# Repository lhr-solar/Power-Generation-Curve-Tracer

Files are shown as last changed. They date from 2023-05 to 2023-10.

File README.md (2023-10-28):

# :sunny: PV Curve Tracer

- [:sunny: PV Curve Tracer](#sunny-pv-curve-tracer)
  - [Repository Structure](#repository-structure)
  - [Maintainers and Contribution](#maintainers-and-contribution)
  - [Versioning](#versioning)
  - [TODO](#todo)

---

## Repository Structure

- **datasheets** - contains datasheets for major components of the PV Curve Tracer.
- **docs** - contains documentation on how to build, test, and use the PV Curve Tracer.
- **fw** - contains fw that is loaded onto the PV Curve Tracer.
  - **tests** - test programs used to characterize and validate the PV Curve Tracer.
  - **src** - main program used to run the PV Curve Tracer.
  - **inc** - internally developed libraries specific for the PV Curve Tracer.
  - **lib** - third party libraries used by the PV Curve Tracer.
- **hw**
  - **Footprints** - project specfic footprint association files for the PV Curve Tracer.
  - **Models** - 3d .step files for the PCB 3d viewer.
  - **Symbols** - project specific symbol files for the PV Curve Tracer.
  - **vX_Y_Z** - frozen versioning folder for PCB production files.

---

## Maintainers and Contribution

The current maintainer of this project is Matthew Yu as of 05/20/2023. His email
is [matthewjkyu@gmail.com](matthewjkyu@gmail.com).

Contributors to the HW and FW encompass many dedicated students, including:

- Roy Mor
- Afnan Mir
- Youssef Elsherif

Special thanks to Professor Gary Hallock, who supervised the development and
design of this project.

---

## Versioning

This PCB is on unified version `1.3.0`. Every time the schematic and/or layout
is updated, this version number should go up. We use [semantic
versioning](https://semver.org/) to denote between versions. See the
[changelog](./docs/CHANGELOG.md) for more details.

---

## TODO

Documentation

- Update assembly and testing document, ordering document, and improvement document.
- Add datasheets for key components of the device.

HW

- check if v1.2.0 bodges has been fixed (op amps, regulator)
   Complete v1.4.0rc board candidate

SW

- Regenerate code for MBED with proposed filestructure

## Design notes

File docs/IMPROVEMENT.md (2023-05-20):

# IMPROVEMENTS FOR PV Curve Tracer

This is a list of changes we can make to the board in future versions to improve
it in various ways. Some of these are functional, others are purely aesthetic.

1. Built in RTD sensor.
2. Secondary UART communication line.
3. Shrink board to sub 100x100mm.
4. Use TM4C for more peripherals?

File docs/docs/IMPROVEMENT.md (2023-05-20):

# IMPROVEMENTS FOR PV Curve Tracer FW

v1.0.0

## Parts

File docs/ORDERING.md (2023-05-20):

# HOW TO ORDER THIS PCB

This guide is on revision `v1.1.0`.

Ordering the board will vary from distributor to distributor; some will take the
KiCAD project directly, others require Gerber files. If they require gerber
files, some will require specific naming conventions for each layer.

## Ordering Instructions: JLCPCB

Our preferred manufacturer (or at least mine) of choice is JLCPCB. They
manufacture hobby boards cheaply and quickly, and at relatively high quality
compared to other fab houses.

JLCPCB will manufacture 5 PCBs for 2$ (sans shipping and handling) if the PCBs
are <= 100mm * 100mm. They also have an SMD assembly surface where one side of
the PCB is populated, often for very cheap prices compared to the amount of
labor you would have to put in to solder all the components on.

For this PCB (Sunscatter), we will order from JLCPCB and also do SMD assembly
from them. KiCAD has nice, open source extensions that can quickly create build
files that JLCPCB will accept for manufacturing and assembly.

### Preparing the Gerbers

First make sure that the JLCPCB plugin is installed via the Plugin and Content
Manager.

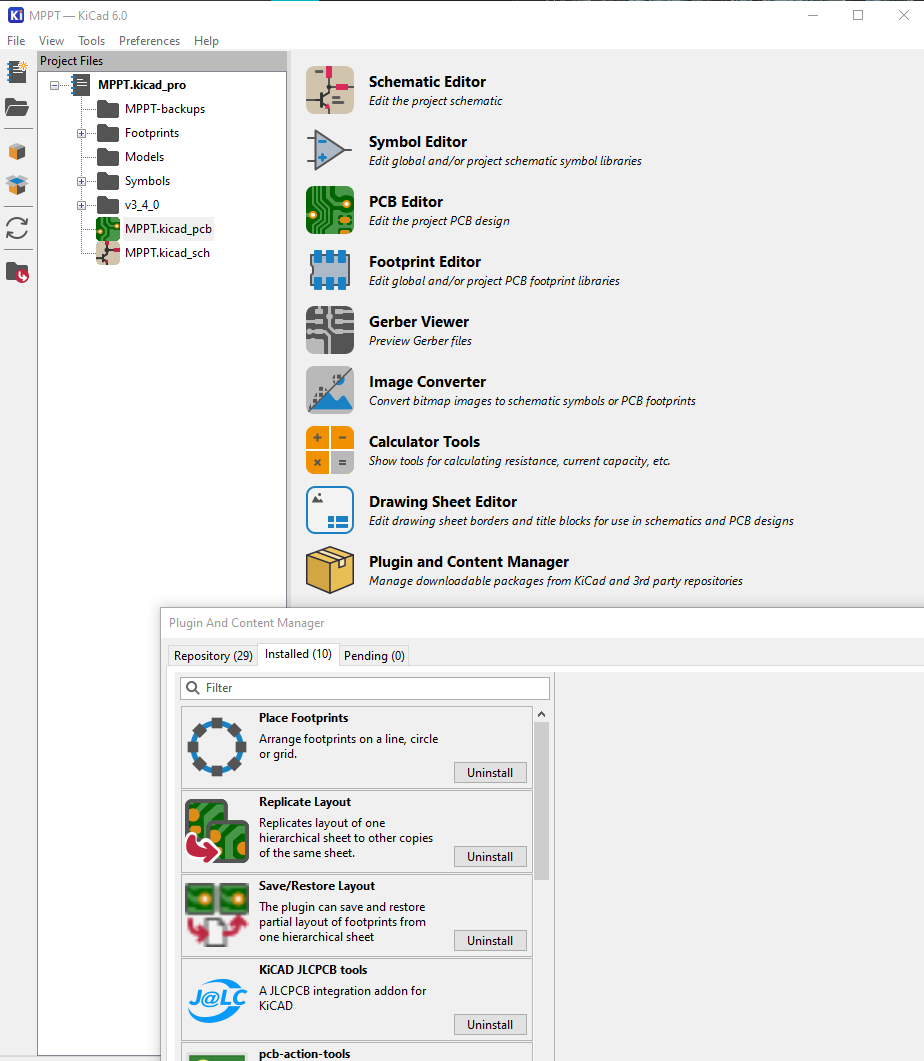
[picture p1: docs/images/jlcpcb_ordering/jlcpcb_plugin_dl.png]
Install plugin


Then make sure your schematic symbol table has following columns populated for
each component:
- Value
- Reference
- Footprint
- JLCPCB BOM
- LCSC Part

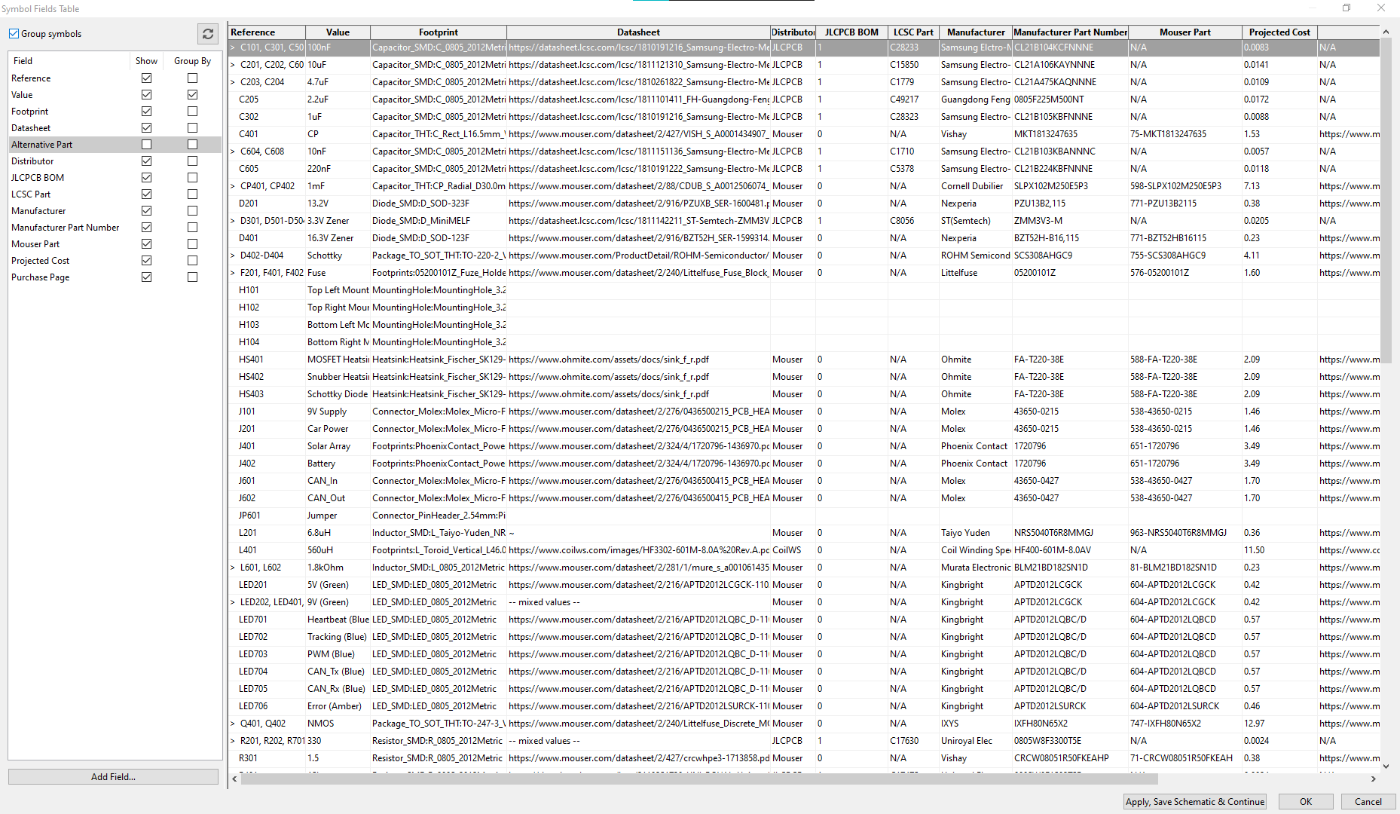
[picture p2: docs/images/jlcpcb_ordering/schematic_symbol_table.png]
Populated symbol table


Go to the PCB editor, and after the layout finishes and everything passes DRC
click on the JLCPCB button.

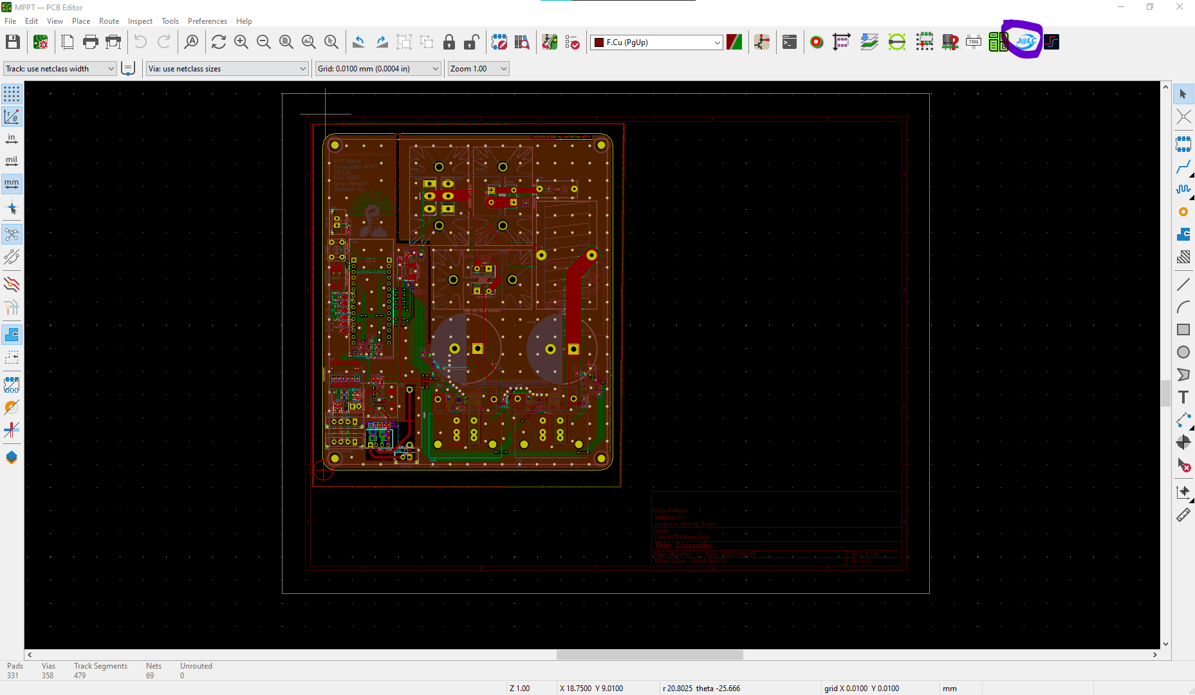
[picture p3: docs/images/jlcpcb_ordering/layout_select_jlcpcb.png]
JLCPCB buttom


Finally generate the fab files using the Generate Fabrication Files button. Make
sure the BOM and POS have a checkmark for all components you want assembled by JLCPCB.

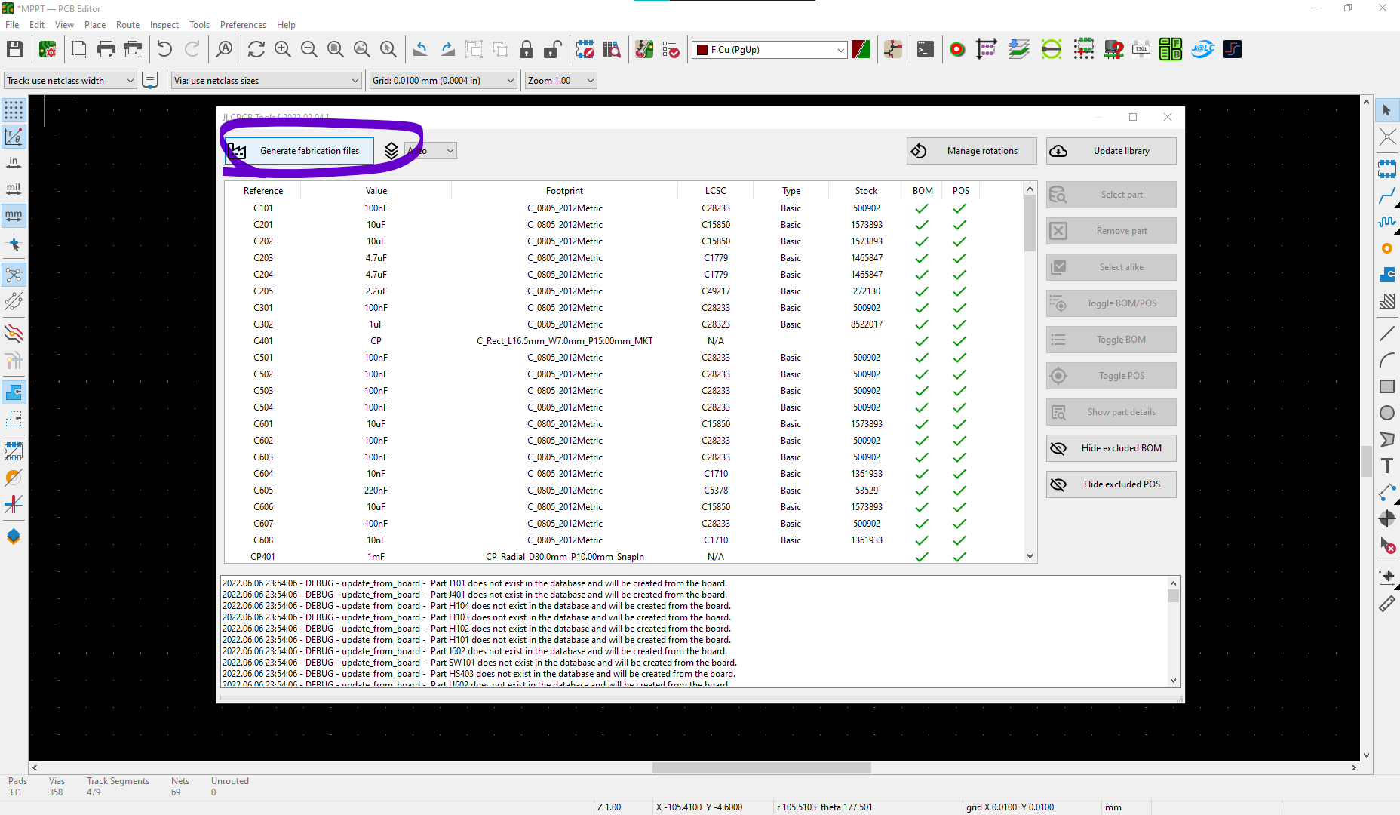
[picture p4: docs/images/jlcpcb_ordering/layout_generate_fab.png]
Generate gerbers


### Ordering from JLCPCB

After the gerbers are generated properly, head onto the JLCPCB
[site](jlcpcb.com).

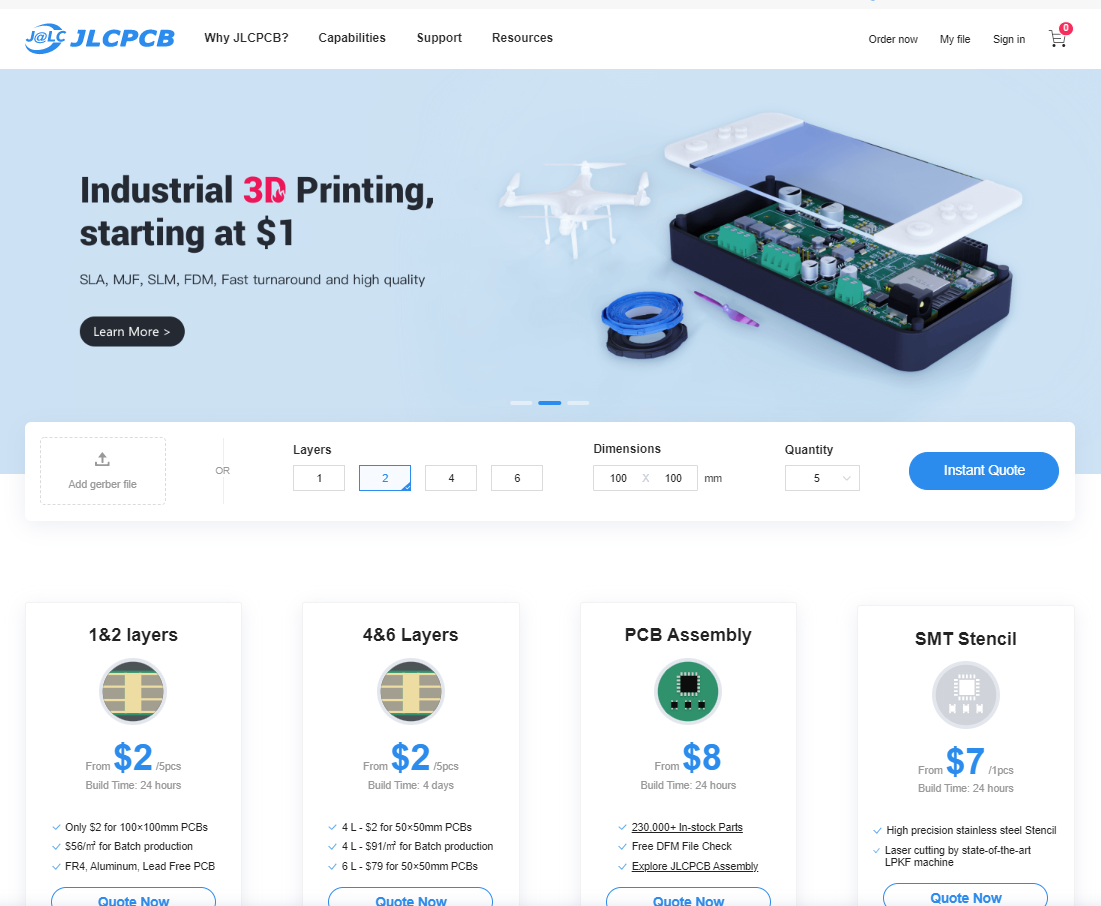
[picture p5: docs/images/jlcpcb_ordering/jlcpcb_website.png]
JLCPCB site


Go and get a quote.

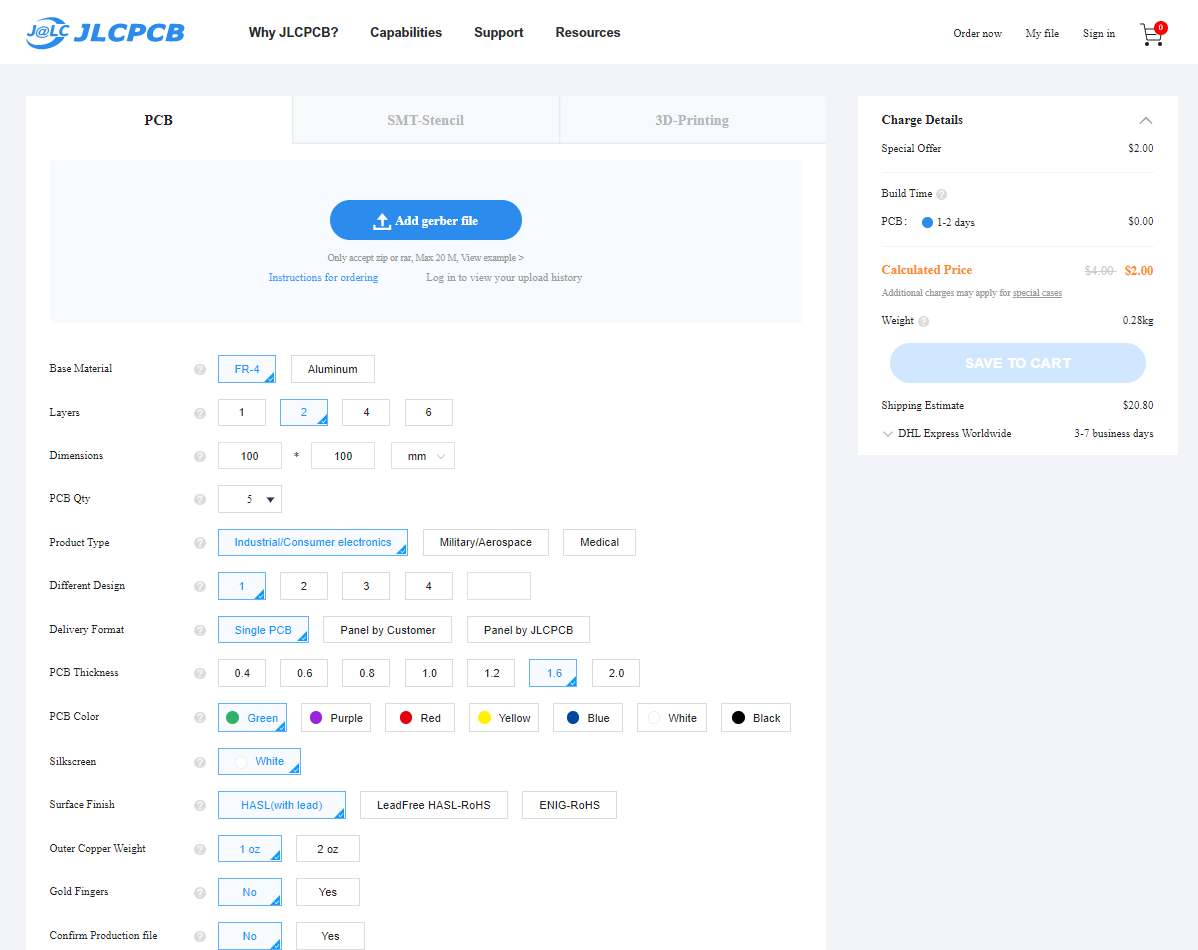
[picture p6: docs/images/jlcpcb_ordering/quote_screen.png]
JLCPCB quote


If you press the add gerber file button, you can upload the output gerber files.
They are found in the `jlcpcb/assembly/gerber` folder as `GERBER-xxx.zip`.

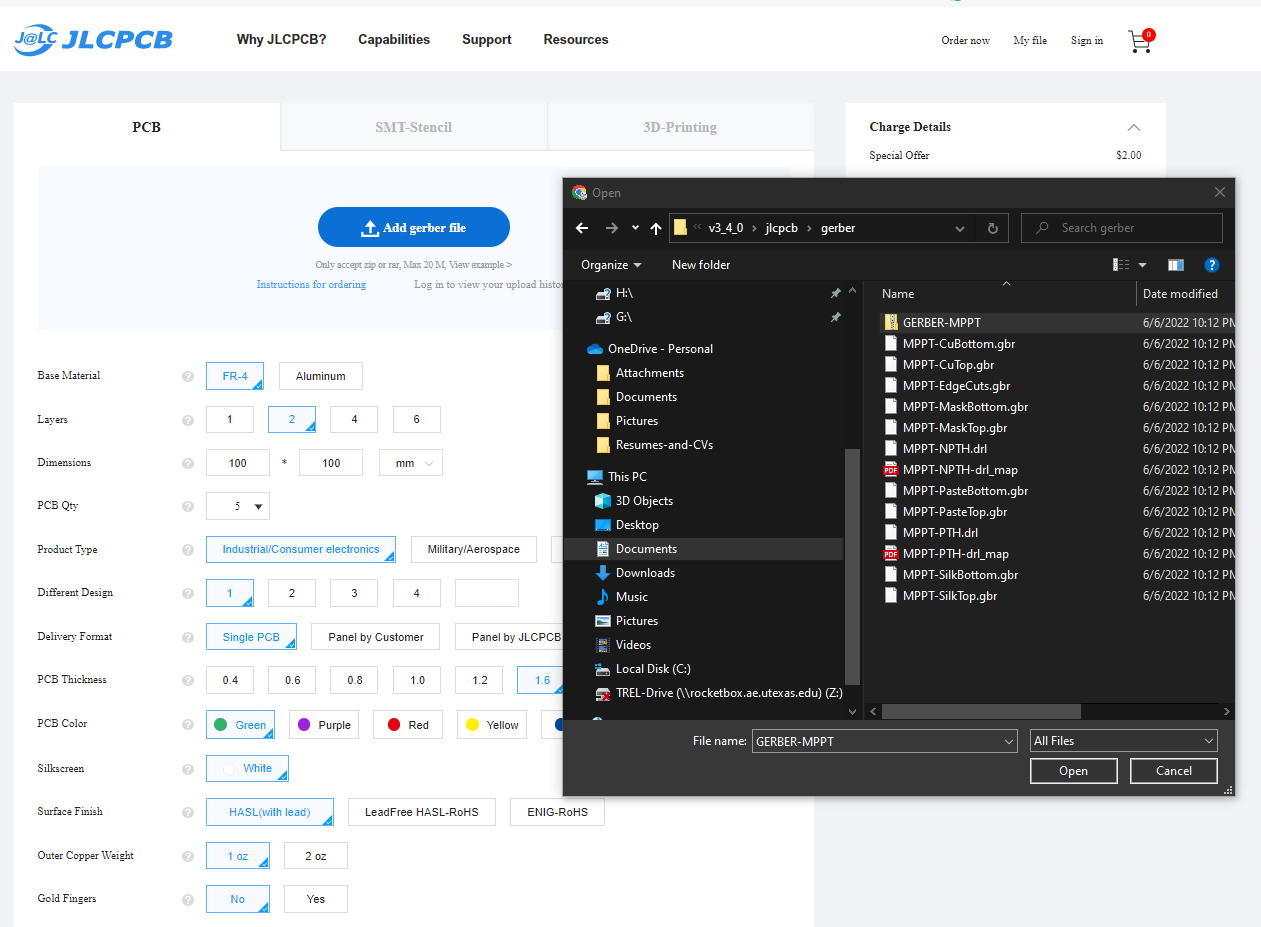
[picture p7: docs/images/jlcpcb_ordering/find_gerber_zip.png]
Adding gerbers


The webpage will load the gerbers, if they are in the correct format and board
passes some checks it'll show up. The dimensions of the board will be updated
and a new quote price will be displayed.

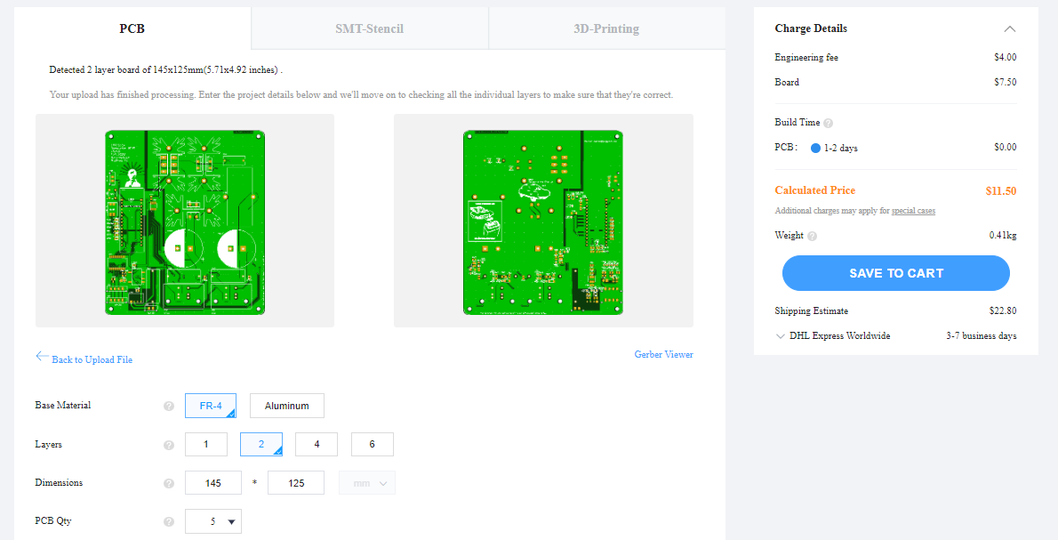
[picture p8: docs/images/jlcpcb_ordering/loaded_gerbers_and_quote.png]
New quote


We can then go down the screen and enable the PCB assembly option. We can choose
which side we want to assemble and the number of boards to assemble (2 or 5).

Assembly option

The next page after hitting confirm asks for a BOM and CPL file, the latter is
the position of the components to be assembled on the board. We can find those
as `jlcpcb/assembly/BOM-xxx.csv` and `jlcpcb/assembly/POS-xxx.csv` respectively.

Assembly file input

The next page will load the BOM and check against the LCSC internal database and
match all available components. We prefer basic components since every extended
component is an extra 2$ fee per type to manually load.

BOM matching

The next page reviews the PCB, you can zoom in on the screen to see where each
component will be placed. Make sure it matches or the engineer who inspects the
files will send an email back with complaints and the order will be delayed.

Review
Zoomed in

Finally you can save the order to the cart, review everything, and order it.
Feel free to select the delivery system that best fits your timeline and the
budget, and use any coupons if you have any.

Shopping Cart

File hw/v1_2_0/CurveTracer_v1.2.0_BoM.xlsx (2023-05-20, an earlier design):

Qty | Reference(s) | Value | Alternative Part | Distributor | Manufacturer | Part Number | Projected Cost | Purchase Page
1 | J2 | 1720819 |  | Allied | Phoenix Connector | 1720819 | 7.09 | https://www.alliedelec.com/product/phoenix-contact/1720819/71247925/
1 | F1 | Fuse |  | Mouser | Littelfuse | 576-05200101Z | 1.6 | https://www.mouser.com/ProductDetail/Littelfuse/05200101Z?qs=gu7KAQ731URy7T5v0X5a9A%3D%3D
1 | HS1 | Heatsink |  | Mouser | Ohmite | 588-FA-T220-38E | 2.09 | https://www.mouser.com/ProductDetail/Ohmite/FA-T220-38E?qs=wmFqszA%252Be7PklmA5Rej7jg%3D%3D
2 | J1, J5 | 1x2 Molex Connector |  | Mouser | Molex | 538-43650-0215 | 1.46 | https://www.mouser.com/ProductDetail/538-43650-0215
2 | J3, J4 | 1x4 Molex Connector |  | Mouser | Molex | 538-43650-0427 | 1.7 | https://www.mouser.com/ProductDetail/Molex/43650-0427?qs=yYVs2tXBqMNbk6Zhnc0cBQ%3D%3D
1 | L1 | 6.8uH |  | Mouser | Taiyo Yuden | 963-NRS5040T6R8MMGJ | 0.36 | https://www.mouser.com/ProductDetail/Taiyo-Yuden/NRS5040T6R8MMGJ?qs=y6ZabgHbY%252Bzi5243tSRdMg%3D%3D
2 | L2, L3 | 1.8kOhm |  | Mouser | Murata Electronics | 81-BLM21BD182SN1D | 0.23 | https://www.mouser.com/ProductDetail/Murata-Electronics/BLM21BD182SN1D?qs=sGAEpiMZZMvCgIIVhD0Cyg9cJWfqr1nr
4 | LED1, LED2, LED3, LED4 | Blue LED |  | Mouser | Kingbright | 604-APTD2012LQBCD | 0.57 | https://www.mouser.com/ProductDetail/Kingbright/APTD2012LQBC-D?qs=AQlKX63v8RvDGqprk6aUCg%3D%3D
1 | LED5 | Error (Amber) |  | Mouser | Kingbright | 604-APTD2012LSURCK | 0.46 | https://www.mouser.com/ProductDetail/Kingbright/APTD2012LSURCK?qs=AQlKX63v8RvkMadNvwbkxw%3D%3D
1 | LED6 | 9V (Green) |  | Mouser | Kingbright | 604-APTD2012LCGCK | 0.42 | https://www.mouser.com/ProductDetail/Kingbright/APTD2012LCGCK?qs=AQlKX63v8RvNHN%2F9EGvNTg%3D%3D
2 | Q1, Q2 | IRF100P218XKMA1 |  | Mouser | Infineon Technologies | 726-IPP041N12N3GXK | 7.07 | https://www.mouser.com/ProductDetail/Infineon-Technologies/IPP041N12N3-G?qs=wK%252BoHS4yu56MUKAoSRvNXg%3D%3D
1 | R12 | 2m | https://www.mouser.com/ProductDetail/Bourns/CRF1206-FZ-R002ELF?qs=NoqMqJKvPFJVdeqRsRJxRg%3D%3D | Mouser | ROHM Semiconductor | 755-PMR18EZPFV2L00 | 0.69 | https://www.mouser.com/ProductDetail/ROHM-Semiconductor/PMR18EZPFV2L00?qs=oBjDkOCjPF3F%252BxFCsdw8aQ%3D%3D
2 | R20, R21 | 60.4 |  | Mouser | Vishay/Dale | 71-CRCW080560R4FKEAH | 0.25 | https://www.mouser.com/ProductDetail/Vishay-Dale/CRCW080560R4FKEAHP?qs=40TFAHZMFvcOLVKmRrsypQ%3D%3D
1 | SW1 | SW_Push |  | Mouser | CUI Devices | 179-TS026650BK260SCR | 0.1 | https://www.mouser.com/ProductDetail/CUI-Devices/TS02-66-50-BK-260-SCR-D?qs=A6eO%252BMLsxmQtNldP04biKA%3D%3D
1 | SW2 | A20303RNCG |  | Mouser | C&K | 611-A20303RNCG | 11.86 | https://www.mouser.com/ProductDetail/CK/A20303RNCG?qs=h7H1bHRqGz8QepjhhmWD%2FQ%3D%3D
1 | U1 | MCU_Nucleo_L432KC |  | Mouser | STMicroelectronics | 511-NUCLEO-L432KC | 10.64 | https://www.mouser.com/ProductDetail/STMicroelectronics/NUCLEO-L432KC?qs=qzCNEk%252BRr%252BajjPvxjwWK5g%3D%3D
1 | U2 | IES01_PDS1 | https://www.mouser.com/ProductDetail/CUI-Inc/PDS1-S5-S9-M-TR?qs=WyjlAZoYn52QMcZg5rCl5g%3D%3D | Mouser | XP Power | 209-IES0105S09 | 3.6 | https://www.mouser.com/ProductDetail/XP-Power/IES0105S09?qs=Cb2nCFKsA8olKT2yq0l%2FZg%3D%3D
2 | U4, U5 | MAX40075 | https://www.digikey.com/en/products/detail/analog-devices-inc-maxim-integrated/MAX40075AUT-T/8742643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 | Mouser | Maxim Integrated | 700-MAX40075AUT+ | 2.13 | https://www.mouser.com/ProductDetail/Maxim-Integrated/MAX40075AUT%2b?qs=rrS6PyfT74cbt4ErCTtr0Q%3D%3D
1 | U6 | ADM3055E |  | Mouser | Analog Devices | 584-ADM3055EBRIZ | 14.91 | https://www.mouser.com/ProductDetail/Analog-Devices/ADM3055EBRIZ?qs=w%2Fv1CP2dgqo%2F70Yob%2FS6iA%3D%3D
1 | U7 | CDSOT23-T24CAN |  | Mouser | Bourns | 652-CDSOT23-T24CAN-Q | 0.5 | https://www.mouser.com/ProductDetail/Bourns/CDSOT23-T24CAN-Q?qs=xhbEVWpZdWdLN7nyBILlNA%3D%3D
1 | U3 | INA210 |  | Texas Instruments | Texas Instruments | INA210AIDCKT | 1.156 | https://www.ti.com/store/ti/en/p/product/?p=INA210AIDCKT
 |  | Light grey - we have already
 |  | Light green - in mouser cart
 |  | Light orange - needs custom order
https://www.mouser.com/ProjectManager/ProjectDetail.aspx?AccessID=4de8ba25e5

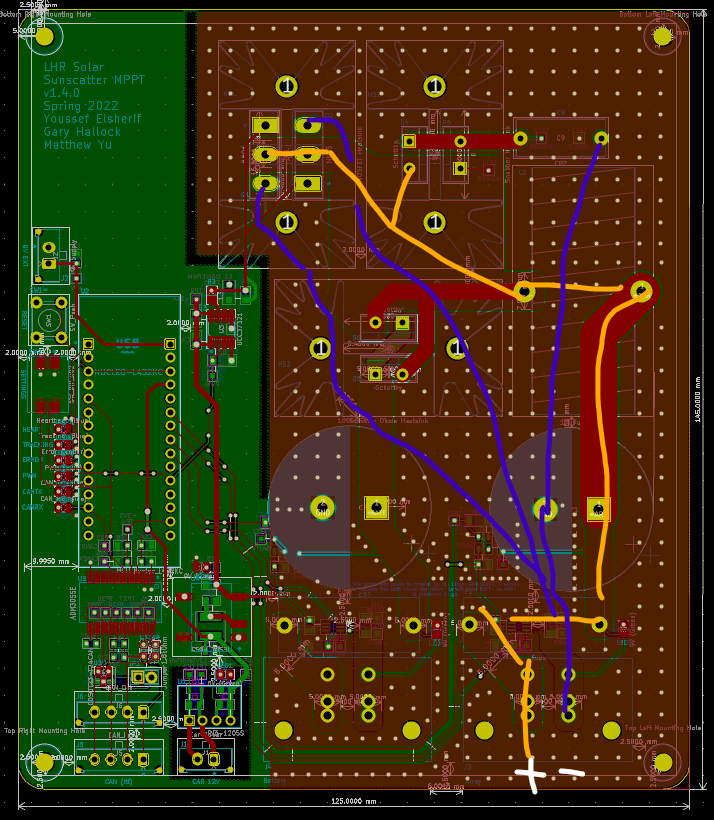
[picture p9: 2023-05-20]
docs/images/jlcpcb_ordering/GateON.png

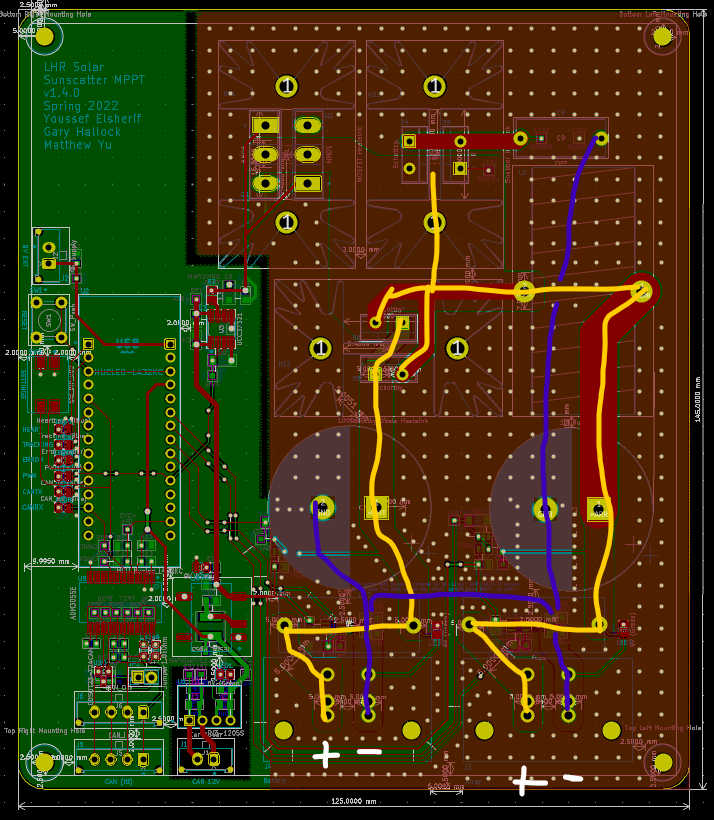
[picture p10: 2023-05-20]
docs/images/jlcpcb_ordering/GateOFF.png

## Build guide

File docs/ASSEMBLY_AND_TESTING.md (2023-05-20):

# HOW TO ASSEMBLE AND TEST THIS PCB

v1.1.0

## Assembly and Testing Instructions

### v1.1.0

The board should be assembled and tested in sections to ensure proper
functioning. Assembly should go through the following sections in order:

1. LEDs
2. Nucleo Connections
3. DC-DC Converter
4. Gate Amplifier
5. Current Sensor
6. Voltage Sensor
7. PV Controller
8. CAN

#### Step by Step Instructions

It's highly recommended to pull up the schematic and layout side by side while
assembling and testing the board. As a tip, you can click on the schematic
symbol, and if the layout window is open, it'll jump to that part on the layout.
Also hide everything except the Silkscreen or Fabrication layer (of the right
side of the PCB) to remove any clutter from the layout.

Also, if you find any discrepancies between these instructions and the board
layout, please file a PR or issue so it can be fixed!

1. Initial Board Checks

   Before installing anything, check for power shorts where there shouldn't be:
   - Between Array + and -
   - Between Device Power +9V and GND
   - Between CAN Iso Vout and GndOut
   - Between CAN Iso Vin and GndIn
   - Between CAN Iso Vout and Vin
   - Between CAN Iso GndOut and GndIn

   Other important shorts to check for and eliminate:
   - Between CAN H and L
   - Between MOSFET terminals
   - Rotary Switch pin 13 and pin 14, and versus GND
   - Between heat sinks and ground
   - On each Nucleo board, between A4 and D4 (shorted by SB18)
   - On each Nucleo board, between A5 and D5 (shorted by SB16)

2. Assembling LEDs

   1. Solder the smallest components first: R1 - R5 and LED1 - LED5.
   2. Check for shorts across each resistor-LED pair.
   3. Further testing on these will occur in the next step.

3. Nucleo Connections

   1. Solder the smallest components first: SW1, C1, J1.
   2. Solder test points: TP1.
   3. Solder the headers for the Nucleo (U1) and make sure they are upright
      and the Nucleo fits.
   4. Test for the following shorts:
      - Across SW1 (shorts only when pushed).
      - Between pins on U1 if you're bored.
   5. Plug in the Nucleo and then test for shorts between D4 and A4 and between
      D5 and A5. If there are shorts here, you will need to remove SB18 or SB16,
      respectively, from the Nucleo board.

      **YOU MUST DO THIS FOR EVERY NUCLEO YOU PLUG INTO THE MPPT.**

   6. Load up the Nucleo with a test program to cycle LED pins and outputs a PWM
      signal with a non-trivial duty cycle and see if they light up/are correct
      on an O-scope. Unplug the Nucleo from USB, and connect 9V to the 9V
      Connector J1. Make sure the Nucleo powers on again and the test program
      works as expected.
   7. Remove the Nucleo and all sources of power before further assembly.

4. DC-DC Converter

   1. Solder the chip U4 on first. Check for shorts across any of the pins.
   2. Then solder on the capacitors C8 - C11.
   3. Solder test points: TP5.
   4. Plug in the Nucleo and plug in USB power. Make sure you have 5V at VCC,
      and 10V at TP5. Unplug power then the Nucleo when done.

5. Gate Amplifier

   1. Solder the chip U3 on first. Check for shorts across any of the pins.
   2. Solder on components R11 and R12.
   3. Solder test points: TP6.
   4. Plug in the Nucleo and plug in USB power. Make sure you have 10V at pin 8,
      and DAC_Control is shorted to the correct pin on the Nucleo (see
      schematic).
   5. Load a test program that outputs a specific voltage out from the Nucleo
      ADC pin connected to DAC_Control. Make sure at the output, TP6 has 5x the
      voltage. Do this with a set of voltages and see if the amplifier
      relationship is linear. Check the transition time if possible (what is the
      maximum speed we can shift voltages at the output?).

6. Current Sensor

   1. Solder in the chip U2 first. Check for shorts across any of the pins.
   2. Then solder on component R6, R7, C2, C3, D1, D2.
   3. Solder test points: TP3.
   4. Test that TP3 is shorted to the pin associated with Array_Current (see
      schematic). Test that 9V is not shorted to GND across the capacitor C2.
   5. Plug in a 9V power source into connector J1 and check that there is 9V
      across pin 3 and 6 of U2. Unplug the power.

7. Voltage Sensor

   1. Solder on components R8, C7, R9, R10, D3, D4.
   2. Solder test points: TP4.
   3. Test that TP4 is shorted to the pin associated with Array_Voltage (see
      schematic). Test that 10V is not shorted to GND across the capacitor C7.
   4. Soldering C4 - C6 are optional. These signal filter capacitors are
      experimental and can be soldered on when testing with a full cell and
      seeing how the signal noise profiles look like on an O-scope.

8. PV Controller

   1. Solder in the small components R13 - R16 first.
   2. Solder the heatsink HS1.
   3. Solder the MOSFETs Q1, Q2 to HS1 and make sure they are aligned (exposed
      metal plate to the heatsink). If they aren't according to the schematic,
      we might need a bodge.
   4. Then solder the fuse F1 and connector J2.
   5. Solder the rotary switch SW2.
   6. Finally, solder test points: TP6.
   7. Test that the fuse contacts are open unless a fuse is inserted. Test that
      Q1 and Q2 pins are tied to each other (they should be facing towards or
      apart from each other so the side pins cross through the center). Test
      that rotary switch connects with the correct resistors and output rotary
      switch pins to Voltage_Sense. You could use an ohm meter to measure pin 13
      to pin 14 and TP6.

9. CAN Circuit

   1. Solder chip U5 **first** and test for shorts across adjacent pins.
   2. Solder the smallest components: C12 - C19, L1, L2, R18, R19.
   3. Solder bridge across R17.
   4. Solder test points TP8 - TP15.
   5. Solder the chip U6.
   6. Solder the termination header JP1.
   7. Solder the CAN Connectors J3, J4.
   8. Test for the following shorts:
      - Between CAN_H and CAN_L.
      - Between CAN_Tx, CAN_Rx.
      - +5V and GNDPWR (Power side).
      - 5V and GND (CAN side).
      - Across adjacent pins in U5, U6.
   9. Plug in the Nucleo, connect J3/J4 to a CAN bus, and run a CAN
      communication test to ensure that the installed CAN circuitry is
      functional.
   10. Remove any power, the Nucleo, and then CAN connections before further
       assembly.

10. Post checks

   Now that you've made it to the end (we hope) of assembly and preliminary
   testing, you should do a couple things before running full MPPT tests and
   running MPPT algorithms on it.

   1. First, check the board for obvious soldering defections like burnt traces
      or exposed component legs. Make sure those still work. For any solder
      bridges that shouldn't fix, you should fix them. Or get somebody who's
      better than you to fix them.
   2. Check to see if you have any remaining parts hiding in the pile of
      plastic packages you probably received. Any remaining parts should
      probably be a cause for concern (unless you knew you were going to blow
      something and had the foresight to get extra) and you should definitely
      see where they might have come from.

      The MPPT Parts list is **THE** definite source of truth, and tells you
      where each part is tied to which reference and thus their position on the
      layout. Check there first before running to the electrical lead to help
      you.
   3. It might be a good idea if you're bored to run any electrical/short tests
      that were described earlier in these instructions. There's always a small
      chance that some assembly you did later on broke/removed/damaged previous
      parts.

### v1.2.0, v1.3.0

> v1.2.0 should be compatible with these instructions, although component
> numbering will be different. Please note any errata from v1.3.0 that should be
> fixed for v1.2.0.

The board should be assembled and tested in sections to ensure proper
functioning. Assembly should go through the following sections in order:

1. Pre Board Checks
2. Power Regulation
3. MCU
4. LEDs
5. CAN Driver
7. Sensors
8. PV Controller
9. Post Board Check

#### Step by Step Instructions

It's highly recommended to pull up the schematic and layout side by side while
assembling and testing the board. As a tip, you can click on the schematic
symbol, and if the layout window is open, it'll jump to that part on the layout.
Also hide everything except the Silkscreen or Fabrication layer (of the right
side of the PCB) to remove any clutter from the layout. You can also use the
provided `ibom.html` (open it in your browser!) for placing components. This is
useful for tracking assembly.

Ideally, JLCPCB or the PCB manufacturer will have assembled most of the board,
if not just the passives. For the components that are already on the board, you
do not need to solder them on, but make sure to test them!

Also, if you find any discrepancies between these instructions and the board
layout, please file a PR or issue so it can be fixed!

##### Soldering Order
1. The recommended order for soldering components are:

    1. Soldering the smallest components.
    2. Solder from the center outwards.
    3. Soldering the back side components.
    4. Soldering the SMD components.
    5. Soldering the through hole components.

    TODO: update this
    An example of this priority system is soldering on the LEDs (LED201,
    LED202) and the SMD converter (U202) prior to the Molex connector (J201)
    and the fuse box (F201).

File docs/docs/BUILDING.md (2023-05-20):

# BUILDING THIS PROGRAM AND FLASHING TO THE PCB

v1.0.0

## Prerequisites

When first initializing this repo, please make sure the `mbed-os` library is in
`inc`. The current version is `6.15.1`. [Mbed
Studio](https://os.mbed.com/studio/) should also be installed.

## Building

When building this project, switch the open workspace to `src`. Mbed Studio will
not recognize that the projects exist without the program folder being at the
root of the workspace.

The appropriate target is the `NUCLEO-L432KC`. This is autopopulated if the
nucleo is plugged into the PC via a USB cable. On the first build, the compile
time will take a while.

An `mbed_app.json` can be added to the program folder. Additional options can be
specified, such as the UART baud rate or the printf precision. See the provided
`mbed_app.json` file in the src subfolders for details.

## Viewing UART/virtual COM serial output

Assuming the HW has the correct UART peripheral pins available to talk via the
USB-UART chip, Mbed Studio has a built in serial monitor for viewing any debug
output.

It is preferred to use PuTTy or a custom serial viewer, however, since the
serial monitor in Mbed Studio may time out after a certain amount of lines.

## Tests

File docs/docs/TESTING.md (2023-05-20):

# HOW TO TEST AND CHARACTERIZE THE HARDWARE

v1.0.0

## TODO: Testing instructions

In addition to the main, defined in `src/Curve_Tracer`, several test and
characterization programs have been created. They are noted briefly here.

- **Indicator Test**: tests LEDs on Sunscatter PCB.
- **CAN Test**: tests CAN peripheral and HW on Sunscatter PCB.
- **Sensor Test**: tests sensor HW and sensor calibration on Sunscatter PCB.
- **Step Response Test**: characterizes the transients for voltage and current
  across the DC-DC converter on the Sunscatter PCB.
- **(*UNDER CONSTRUCTION*)** **Boost Characterization Test**: Characterizes
  unloaded and loaded boost parameters of the DC-DC converter.
- **(*USE FOR ARRAY TESTING*)** **Voltage Sweep MPPT Test**: sweeps across the
  input source and sets a reference at the PWM duty cycle that maximizes either
  efficiency or power transmission.
- **(*UNDER CONSTRUCTION*)** **Curve_Tracer**: main program for the PV Curve
  Tracer PCB.

After building each program and loading them onto the Nucleo, the testing
instructions are as follows. 

---

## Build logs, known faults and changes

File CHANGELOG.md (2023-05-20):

# CHANGELOG

- [CHANGELOG](#changelog)
  - [1.0.0](#100)
  - [1.1.0](#110)
  - [1.2.0](#120)
  - [1.3.0](#130)
  - [1.4.0rc (proposed)](#140rc-proposed)

## 1.0.0

**Schematic**

- First schematic design completed.

**Layout**

- First layout design completed.

**Firmware**

- First FW tests and main program added.

## 1.1.0

- Standardized parts with the MPPT and RTD/Irradiance Sensor parts list.
- Re-selected the rotary switch to make sure it would work for the application.
- Added extra filter capacitor selections for the voltage sensor. Optional to
  use.
- Corrected any parts discrepancies from v1.0.0 parts list.

**Schematic**

- Transitioned component footprints from through hole to SMD as part of the
  parts list synchronization.
- Re-annotated all component labels and removed rescued symbols. We now just
  have a single .pretty folder and an Array.lib.
- Updated indicator LEDs and added a Reset button.
- Standardized current sensor to that on the MPPT board.
- Merged the op amp used by the voltage sensor and the gate amplifier.
- Added a pre-emptive fuse to array input and swapped to a Phoenix connector.
- Added a pre-emptive 9V power supply.

**Layout**

- Shrunk layout footprint by 35%.
- Added extra no fill zones to shield analog, digital, and power sections from
  each other.
- Ensured minimum current rating is 8A.
- Added extra capacitor pads for voltage sensor filtering. Optional to use.

## 1.2.0

- Moved parts list into the KiCAD project.

## 1.3.0

- Versioning is unified between schematic, layout, and BoM.
- This repo is now a subrepo in the Power-Generation monorepo.

**Schematic**

- Schematic is rebuilt in KiCAD v7.x, with any ERC fixes.
- Simplified schematic symbol field table to the following fields:
  - Distributor
  - Manufacturer
  - LCSC Part #
  - P/N
  - Cost

**Layout**

- Layout is rebuilt in KiCAD v7.x, with any DRC fixes.

**Firmware**

- Firmware is rebuilt and optimized for hardware. Added more calibration tests.

## 1.4.0rc (proposed)

- Proposal to further reduce board cost and size without sacrificing efficiency.

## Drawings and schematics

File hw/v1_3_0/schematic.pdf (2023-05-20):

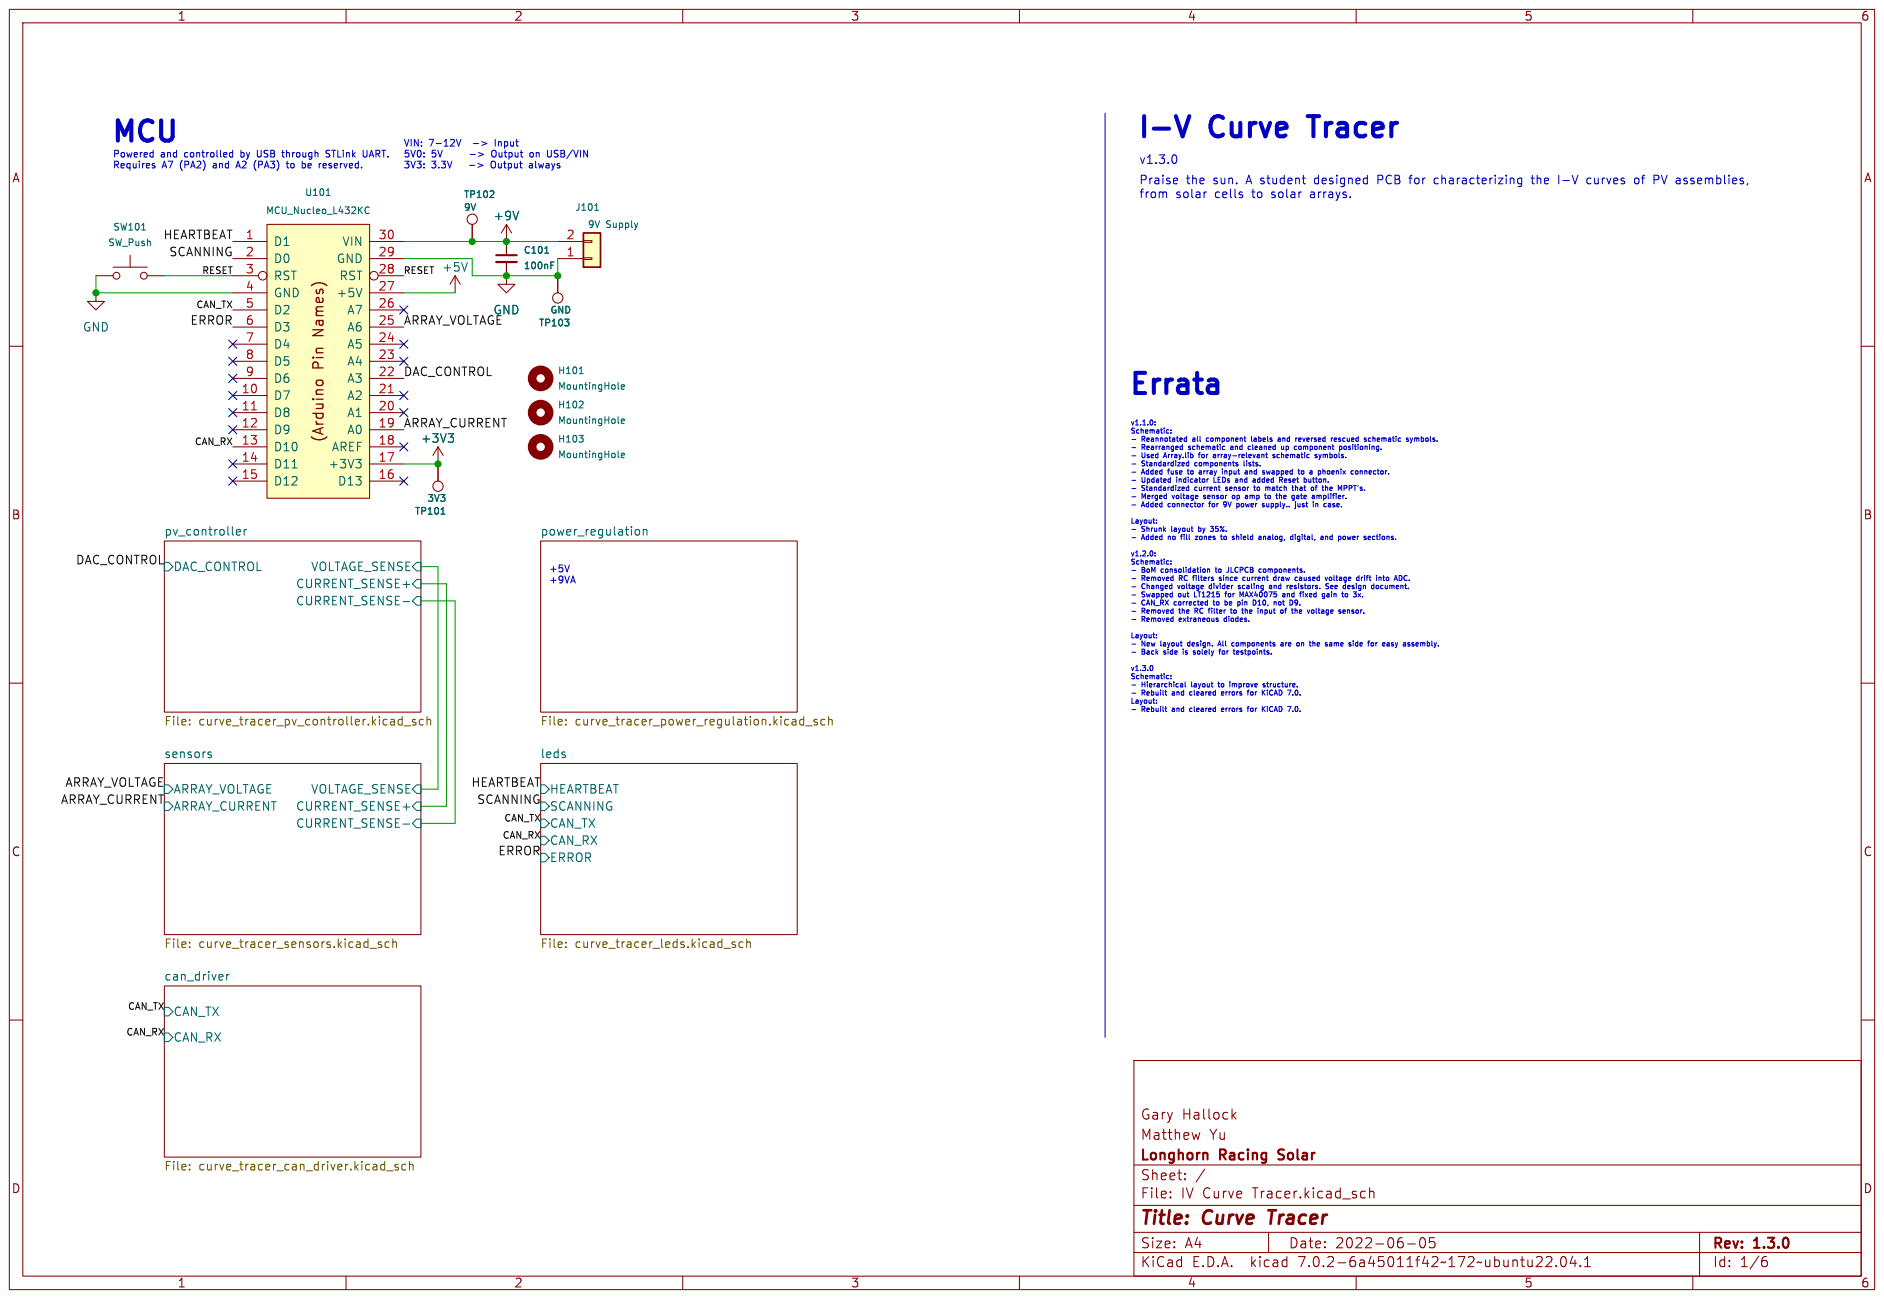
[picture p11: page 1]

from solar cells to solar arrays. +5V

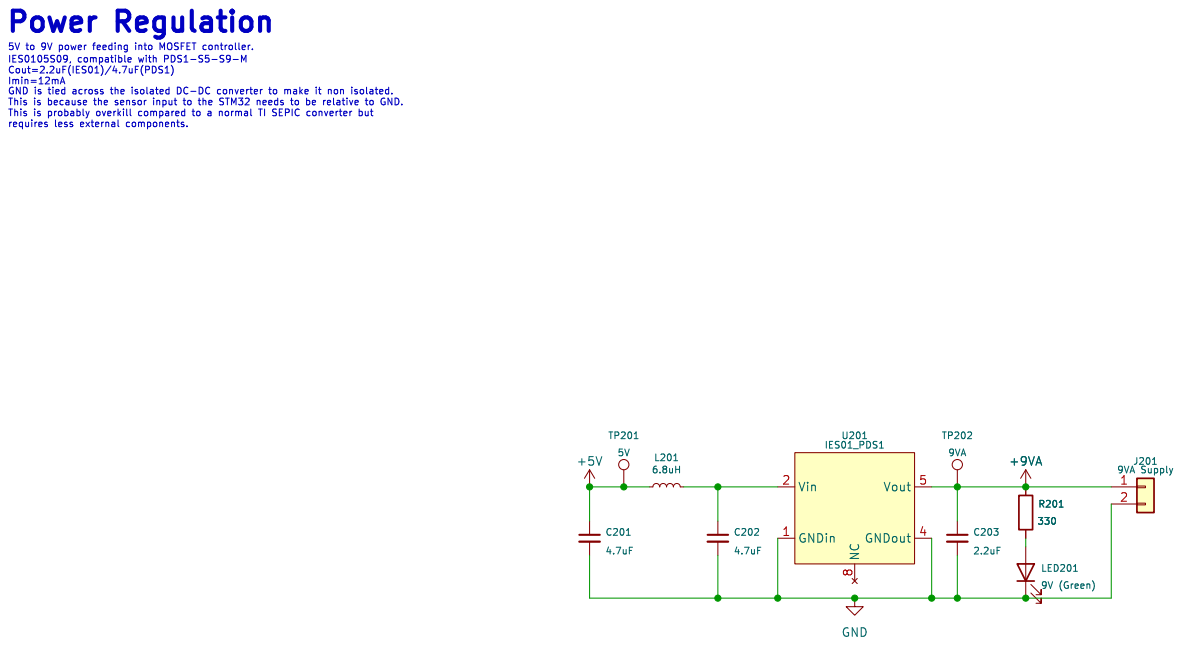
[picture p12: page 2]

Id: 2/6 Title: Curve Tracer File: curve_tracer_power_regulation.kicad_sch Sheet: /power_regulation/

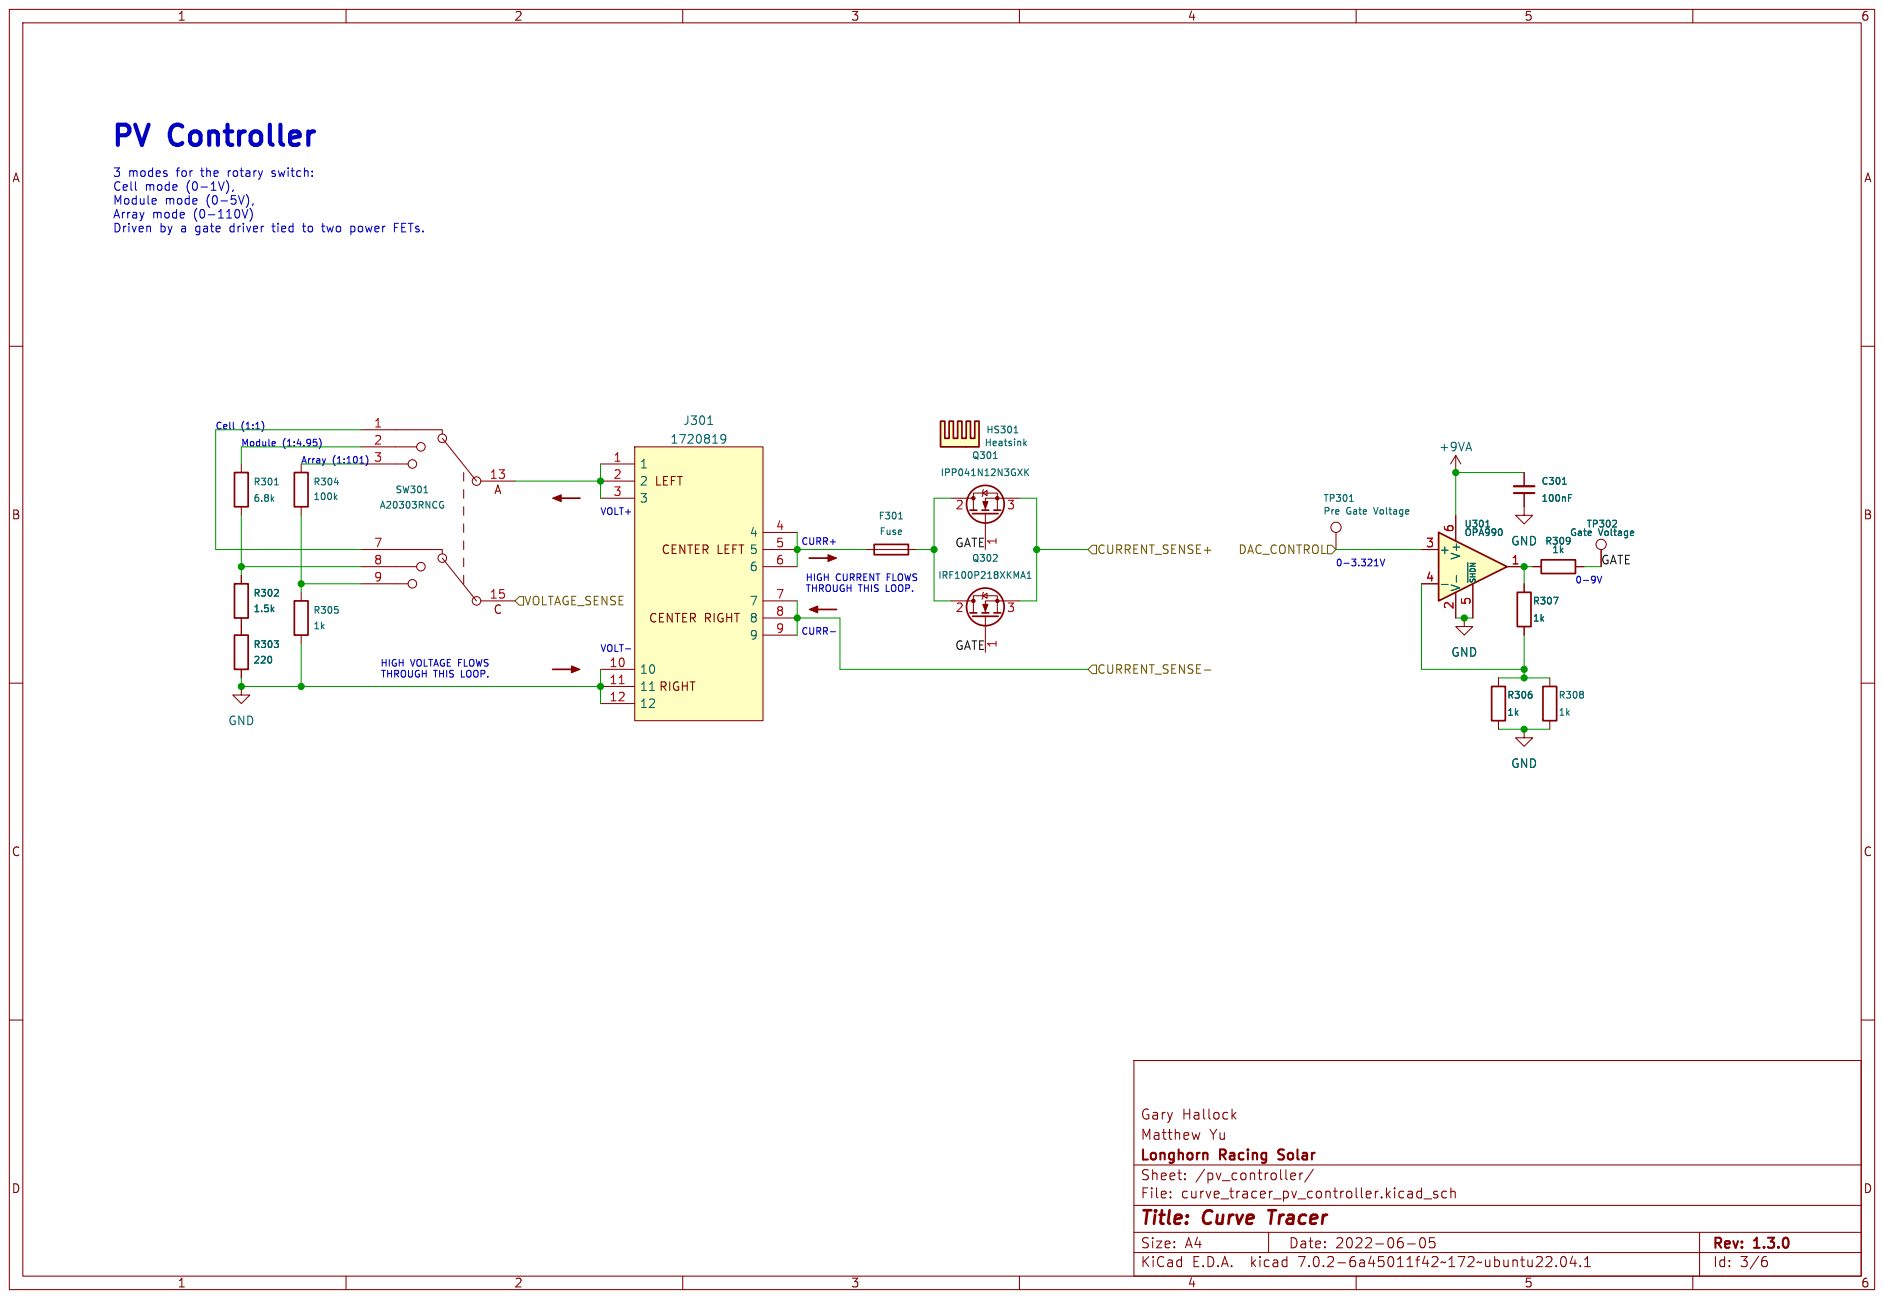
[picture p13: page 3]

3 modes for the rotary switch: Cell mode (0-1V), Module mode (0-5V),

CENTER LEFT CENTER RIGHT

Id: 3/6 Title: Curve Tracer File: curve_tracer_pv_controller.kicad_sch Sheet: /pv_controller/

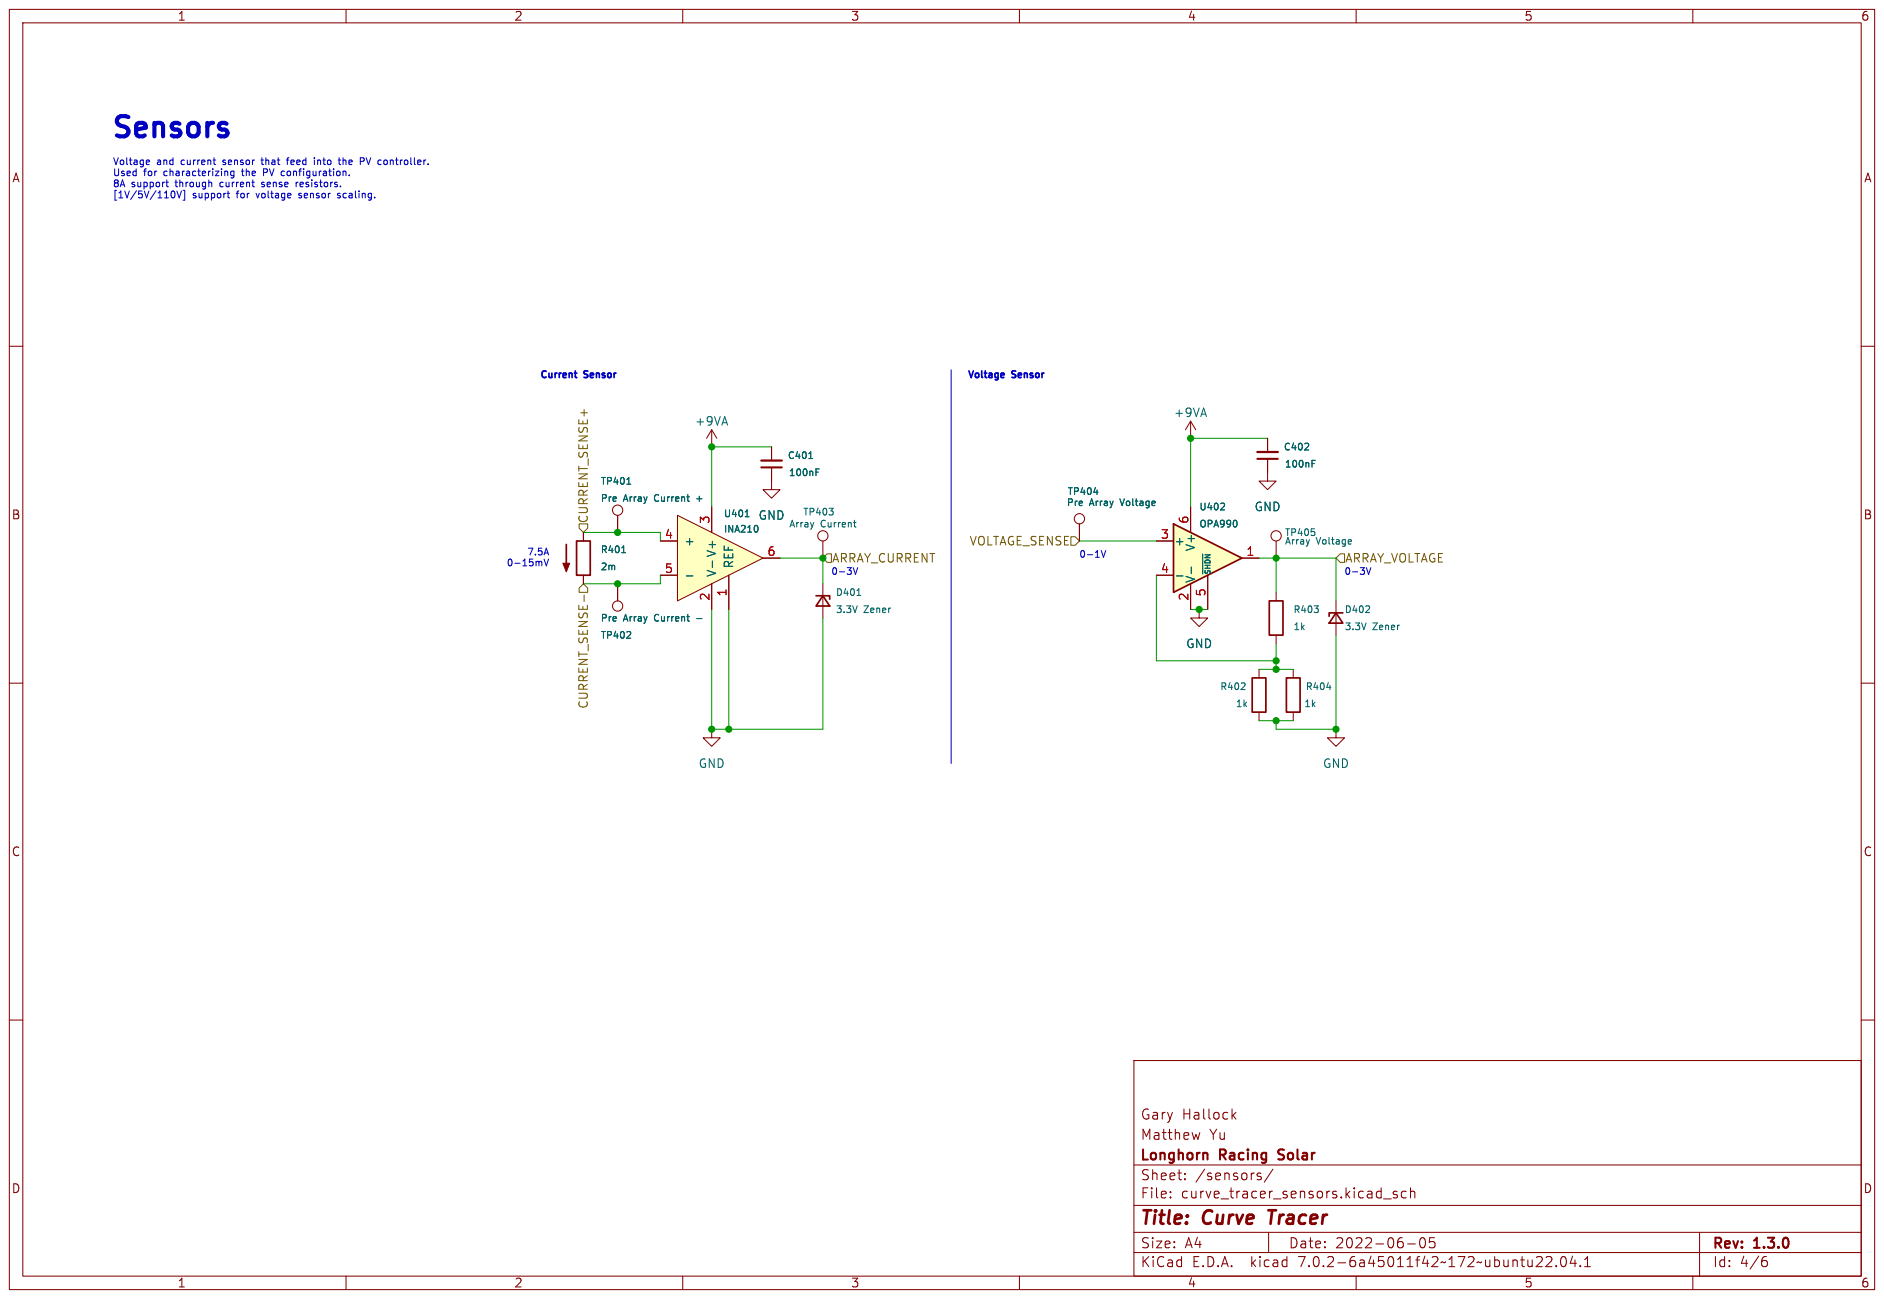
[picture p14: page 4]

TP404 Pre Array Voltage TP401 Pre Array Current + R401

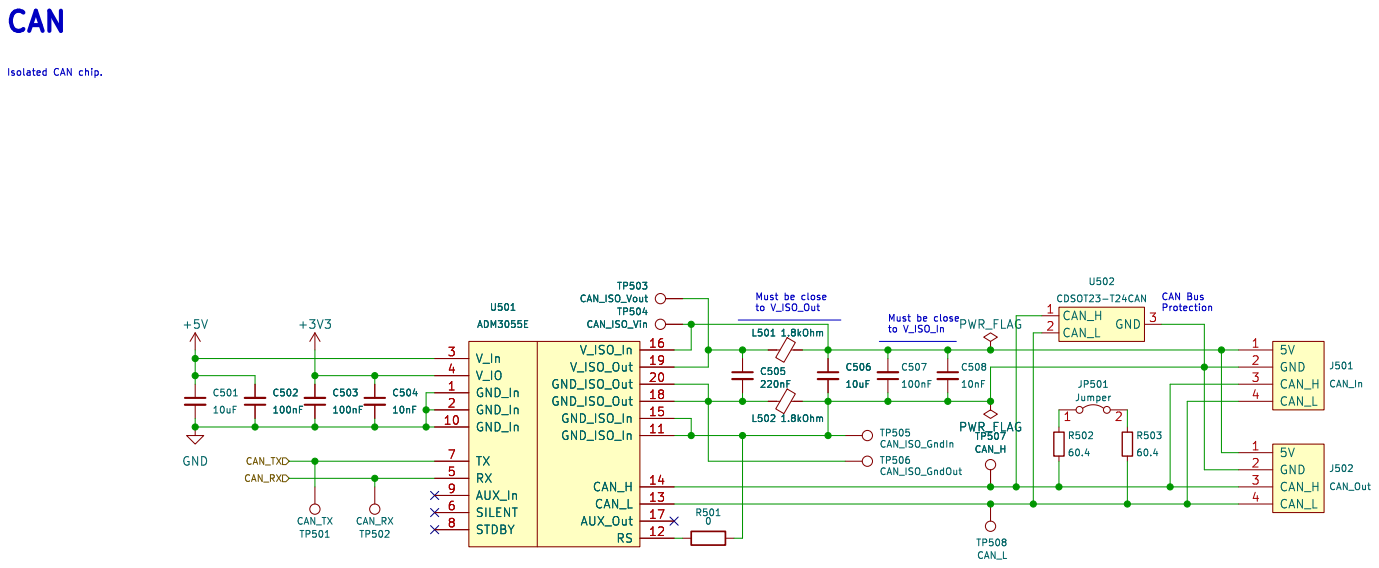
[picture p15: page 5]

to V_ISO_In Must be close
to V_ISO_Out

Id: 5/6 Title: Curve Tracer File: curve_tracer_can_driver.kicad_sch Sheet: /can_driver/

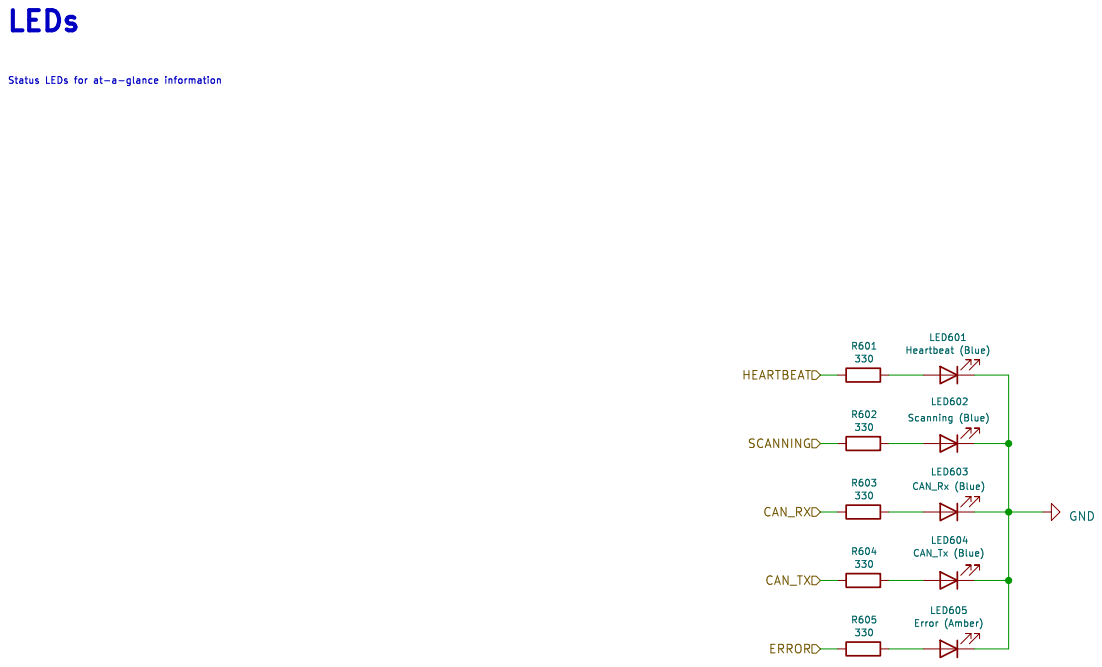
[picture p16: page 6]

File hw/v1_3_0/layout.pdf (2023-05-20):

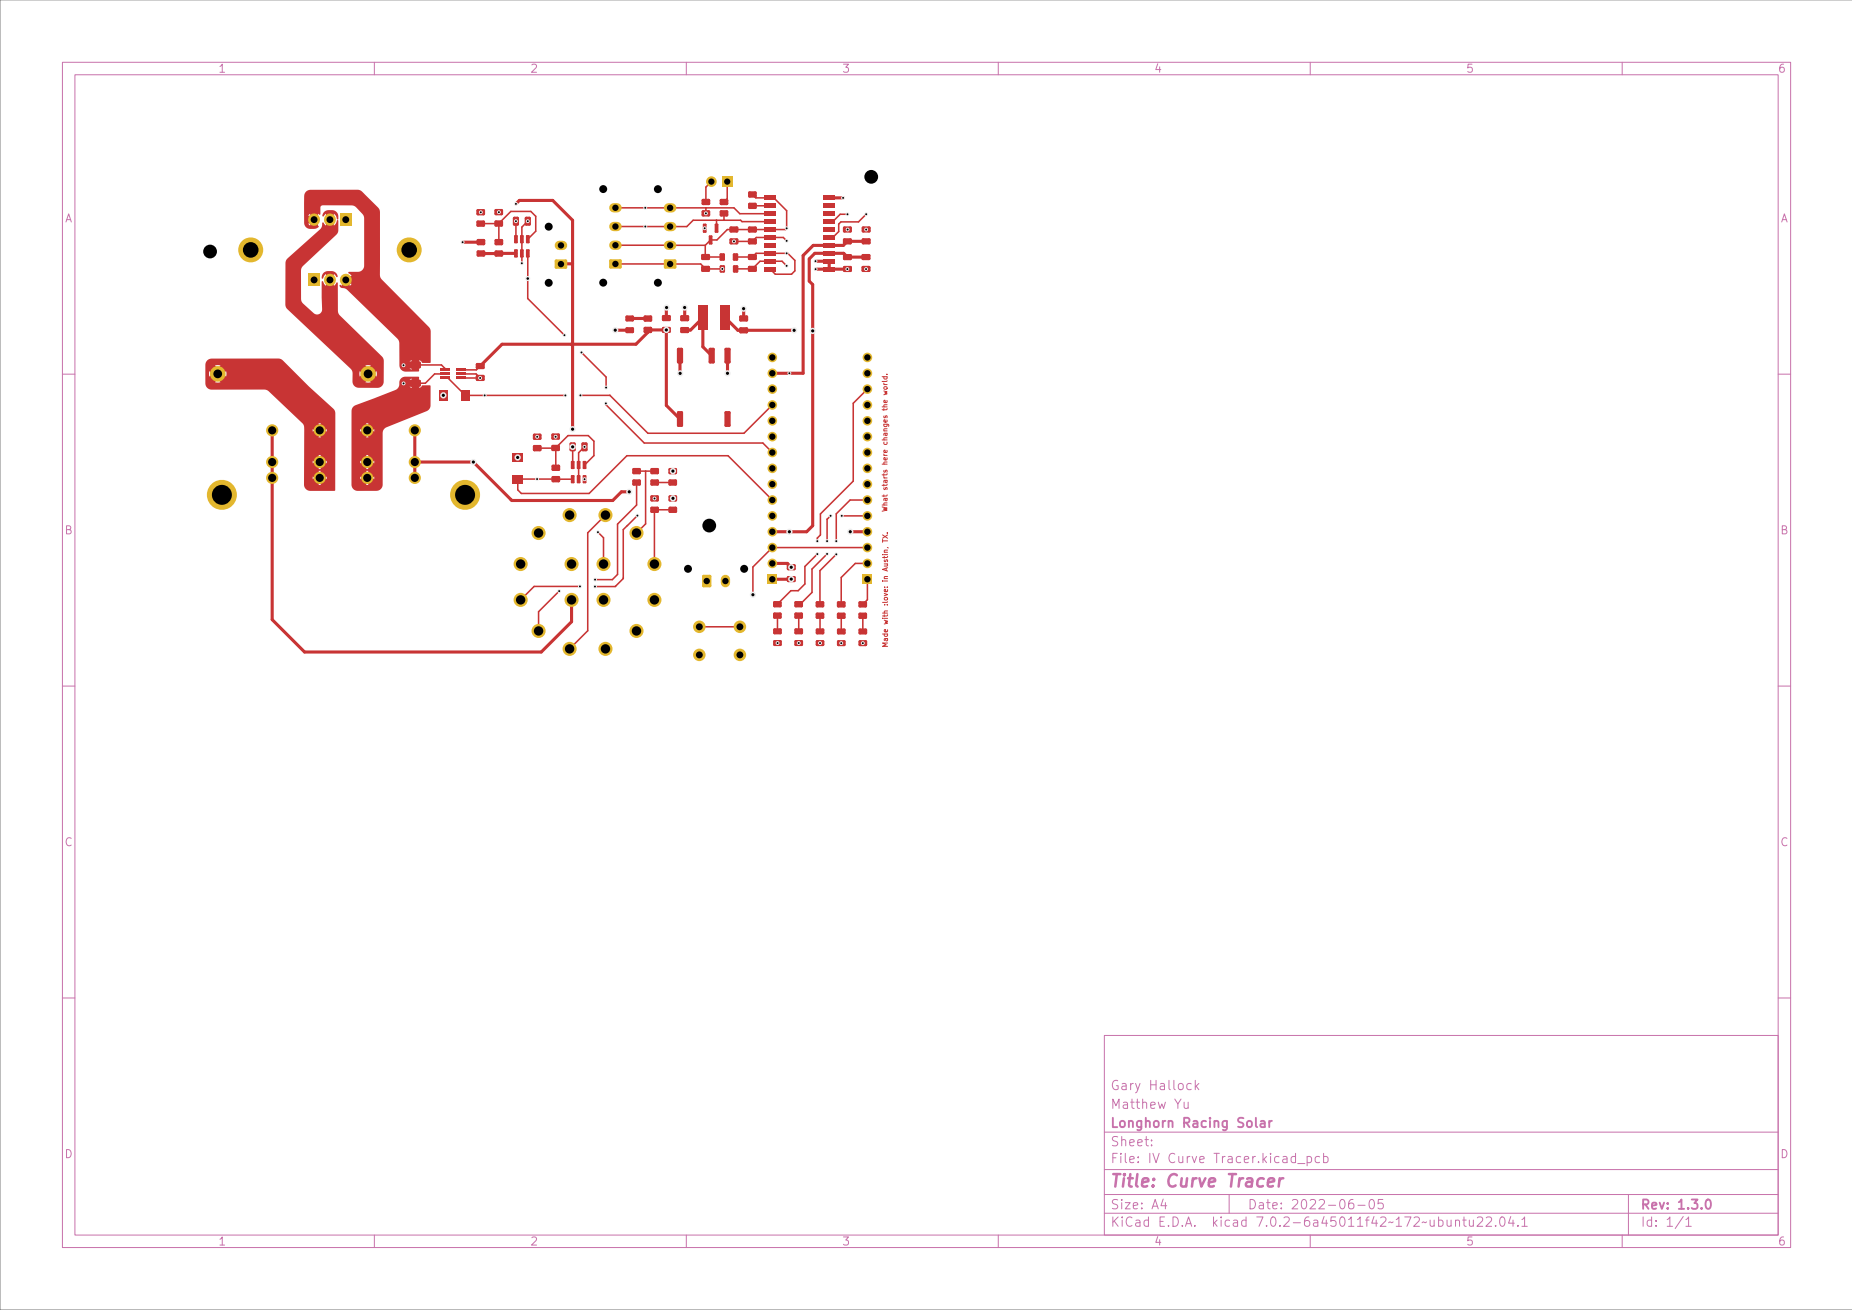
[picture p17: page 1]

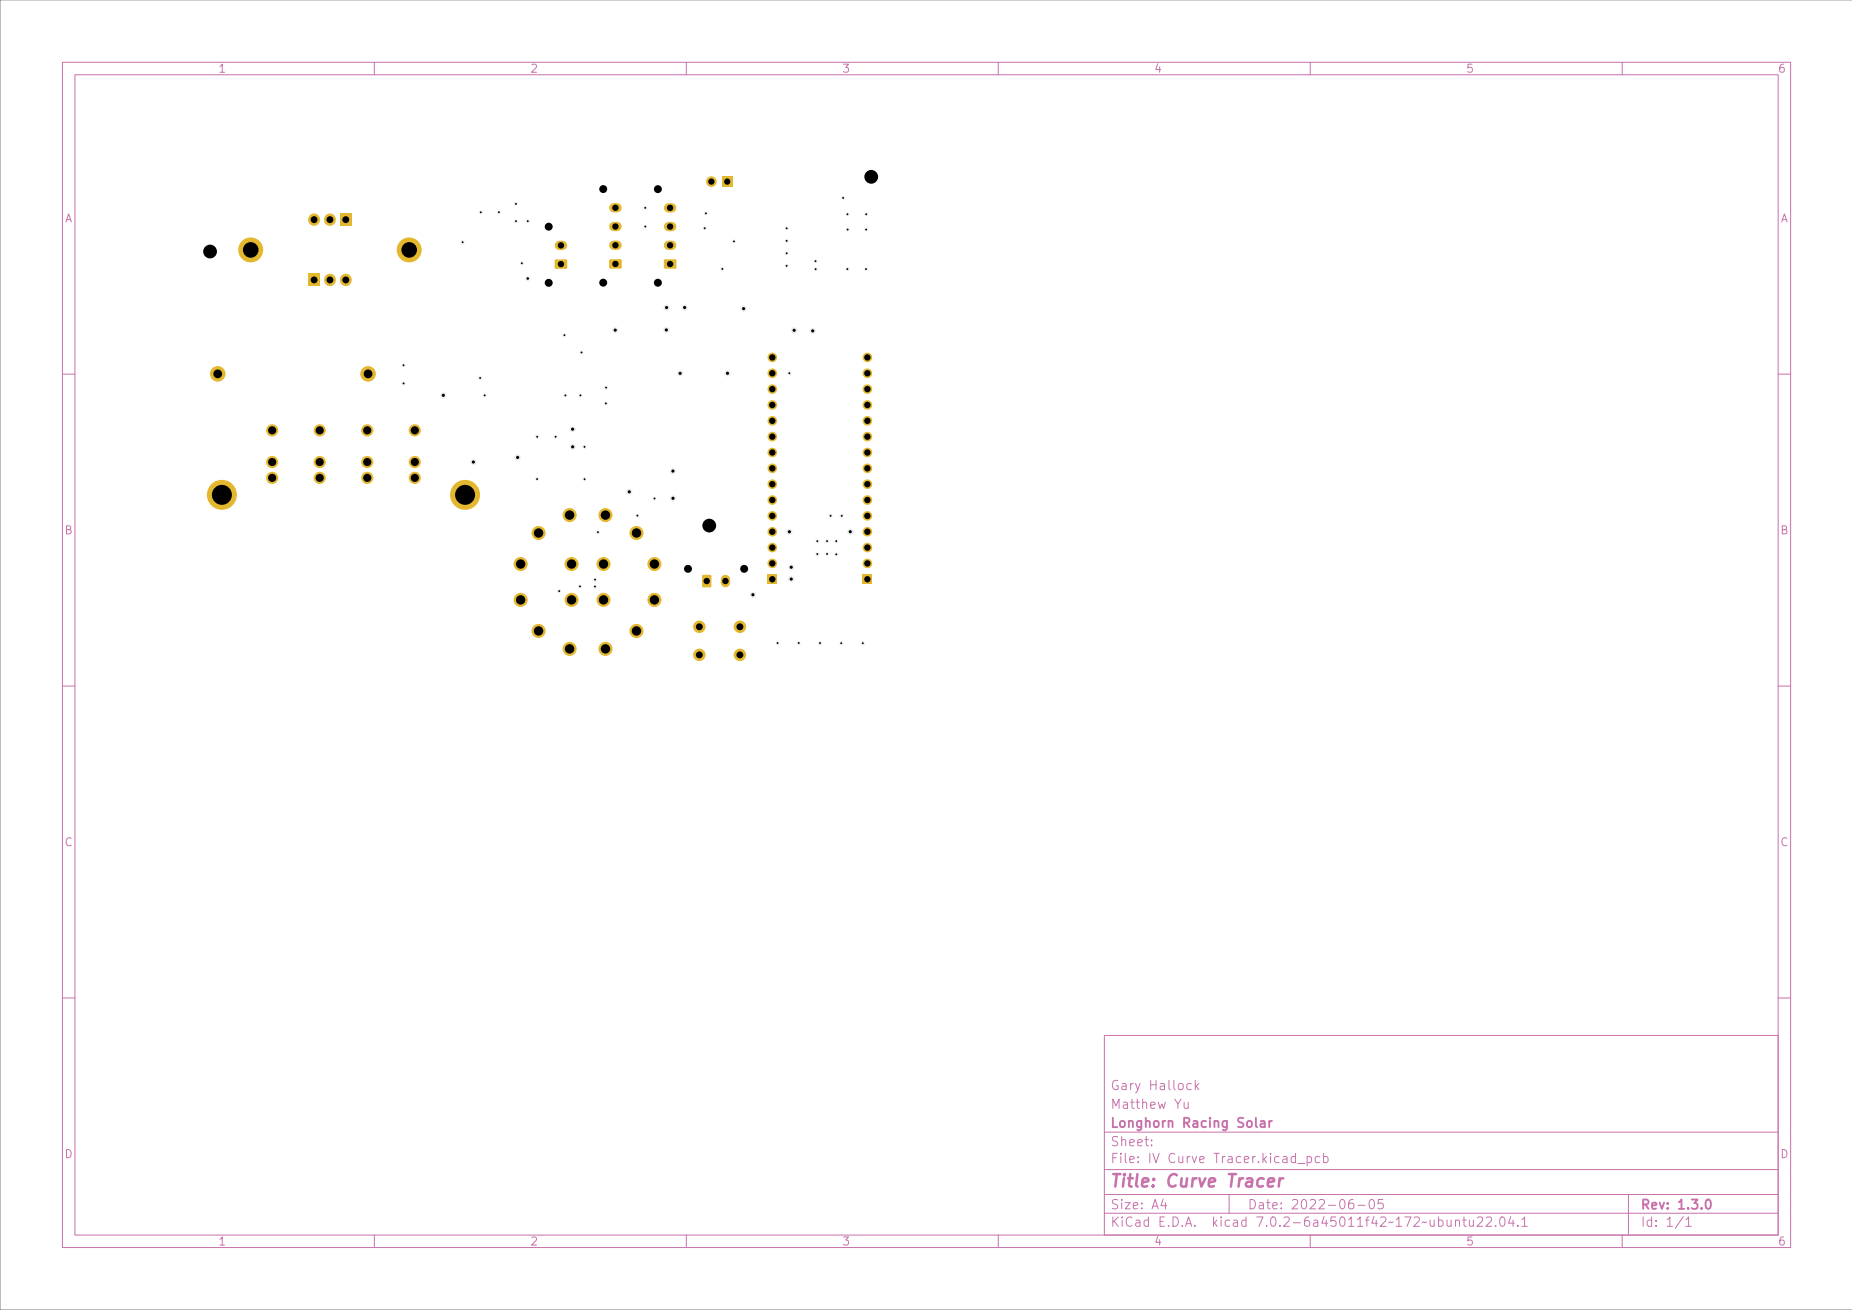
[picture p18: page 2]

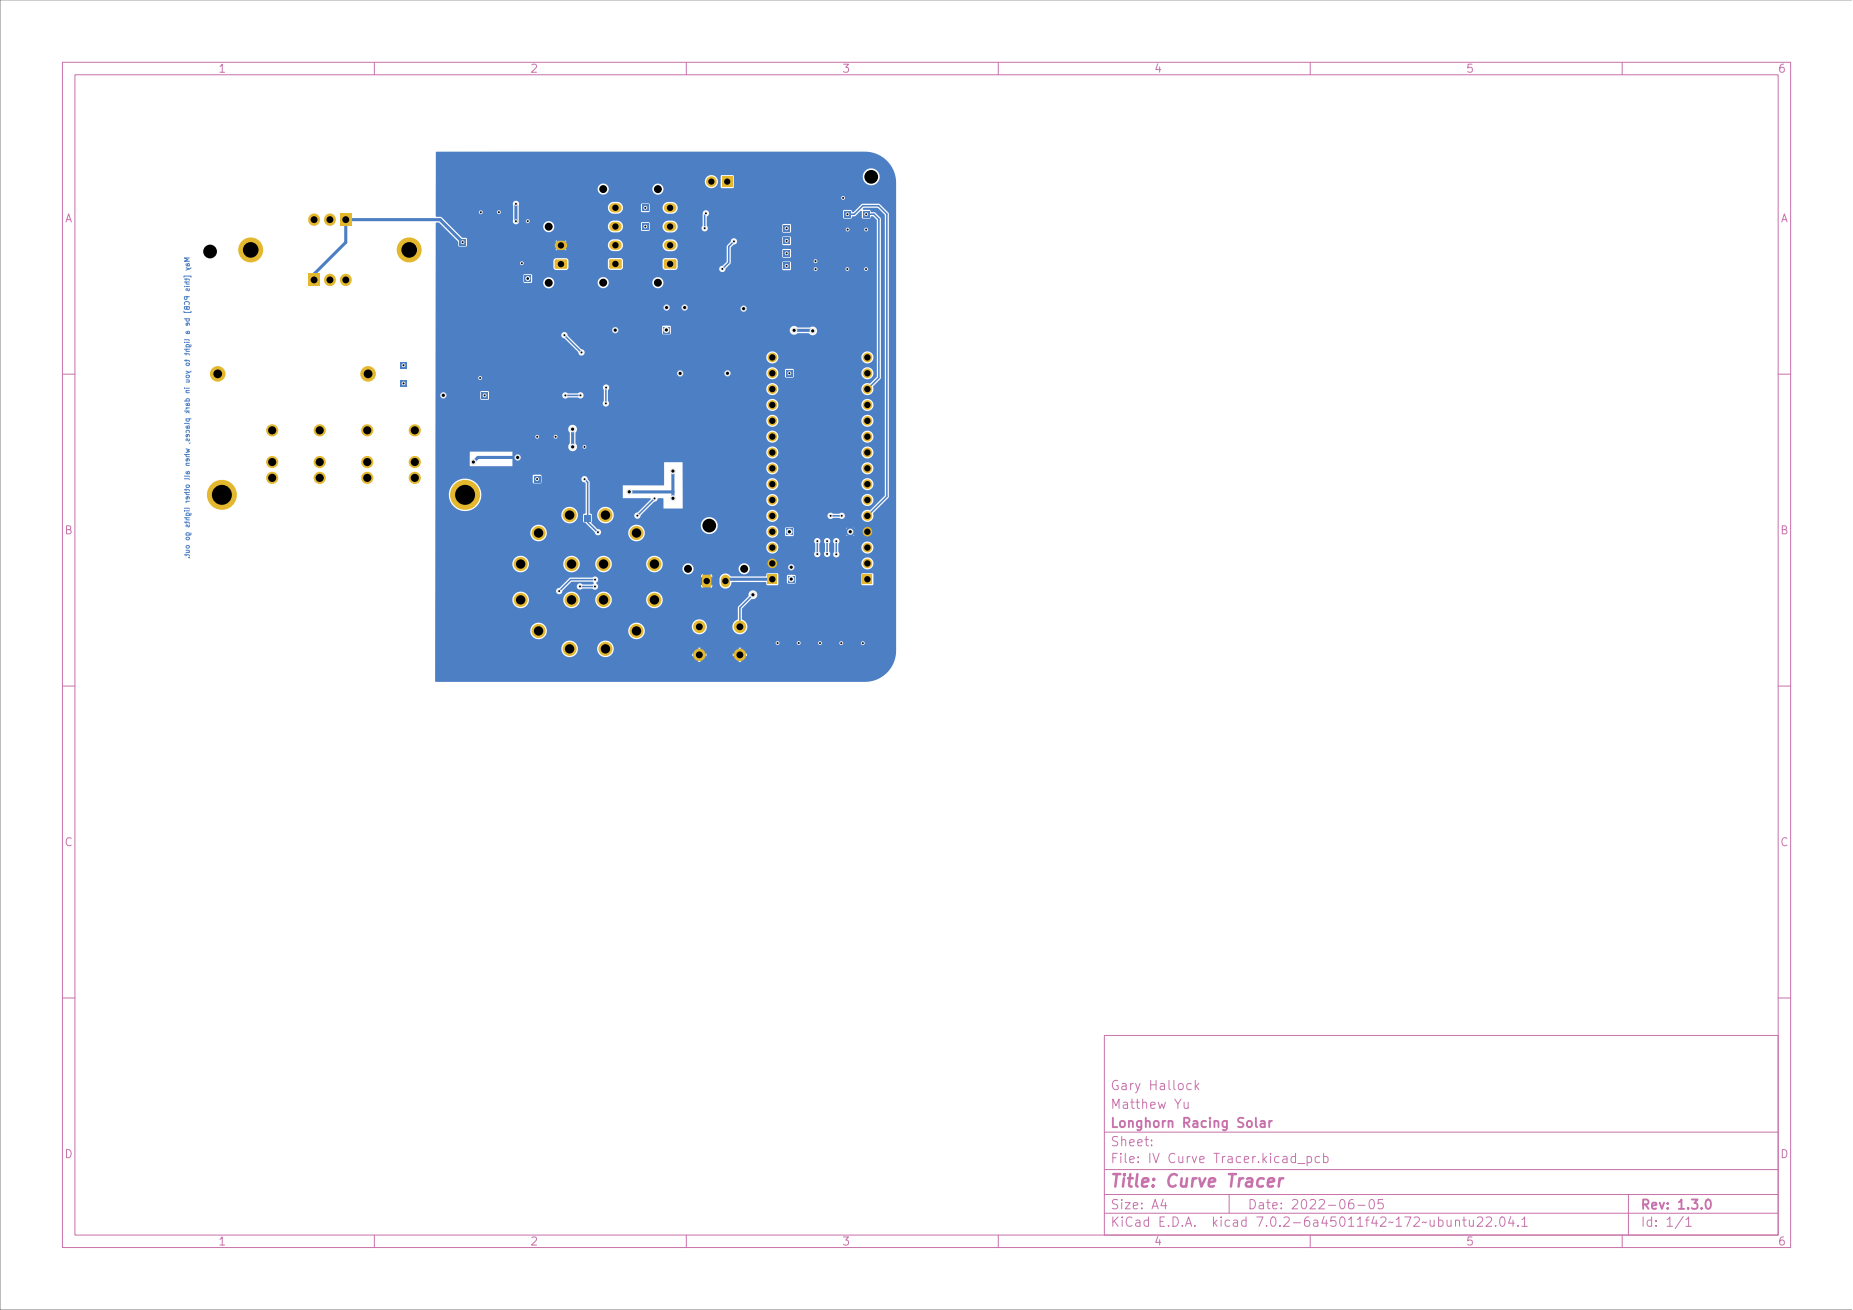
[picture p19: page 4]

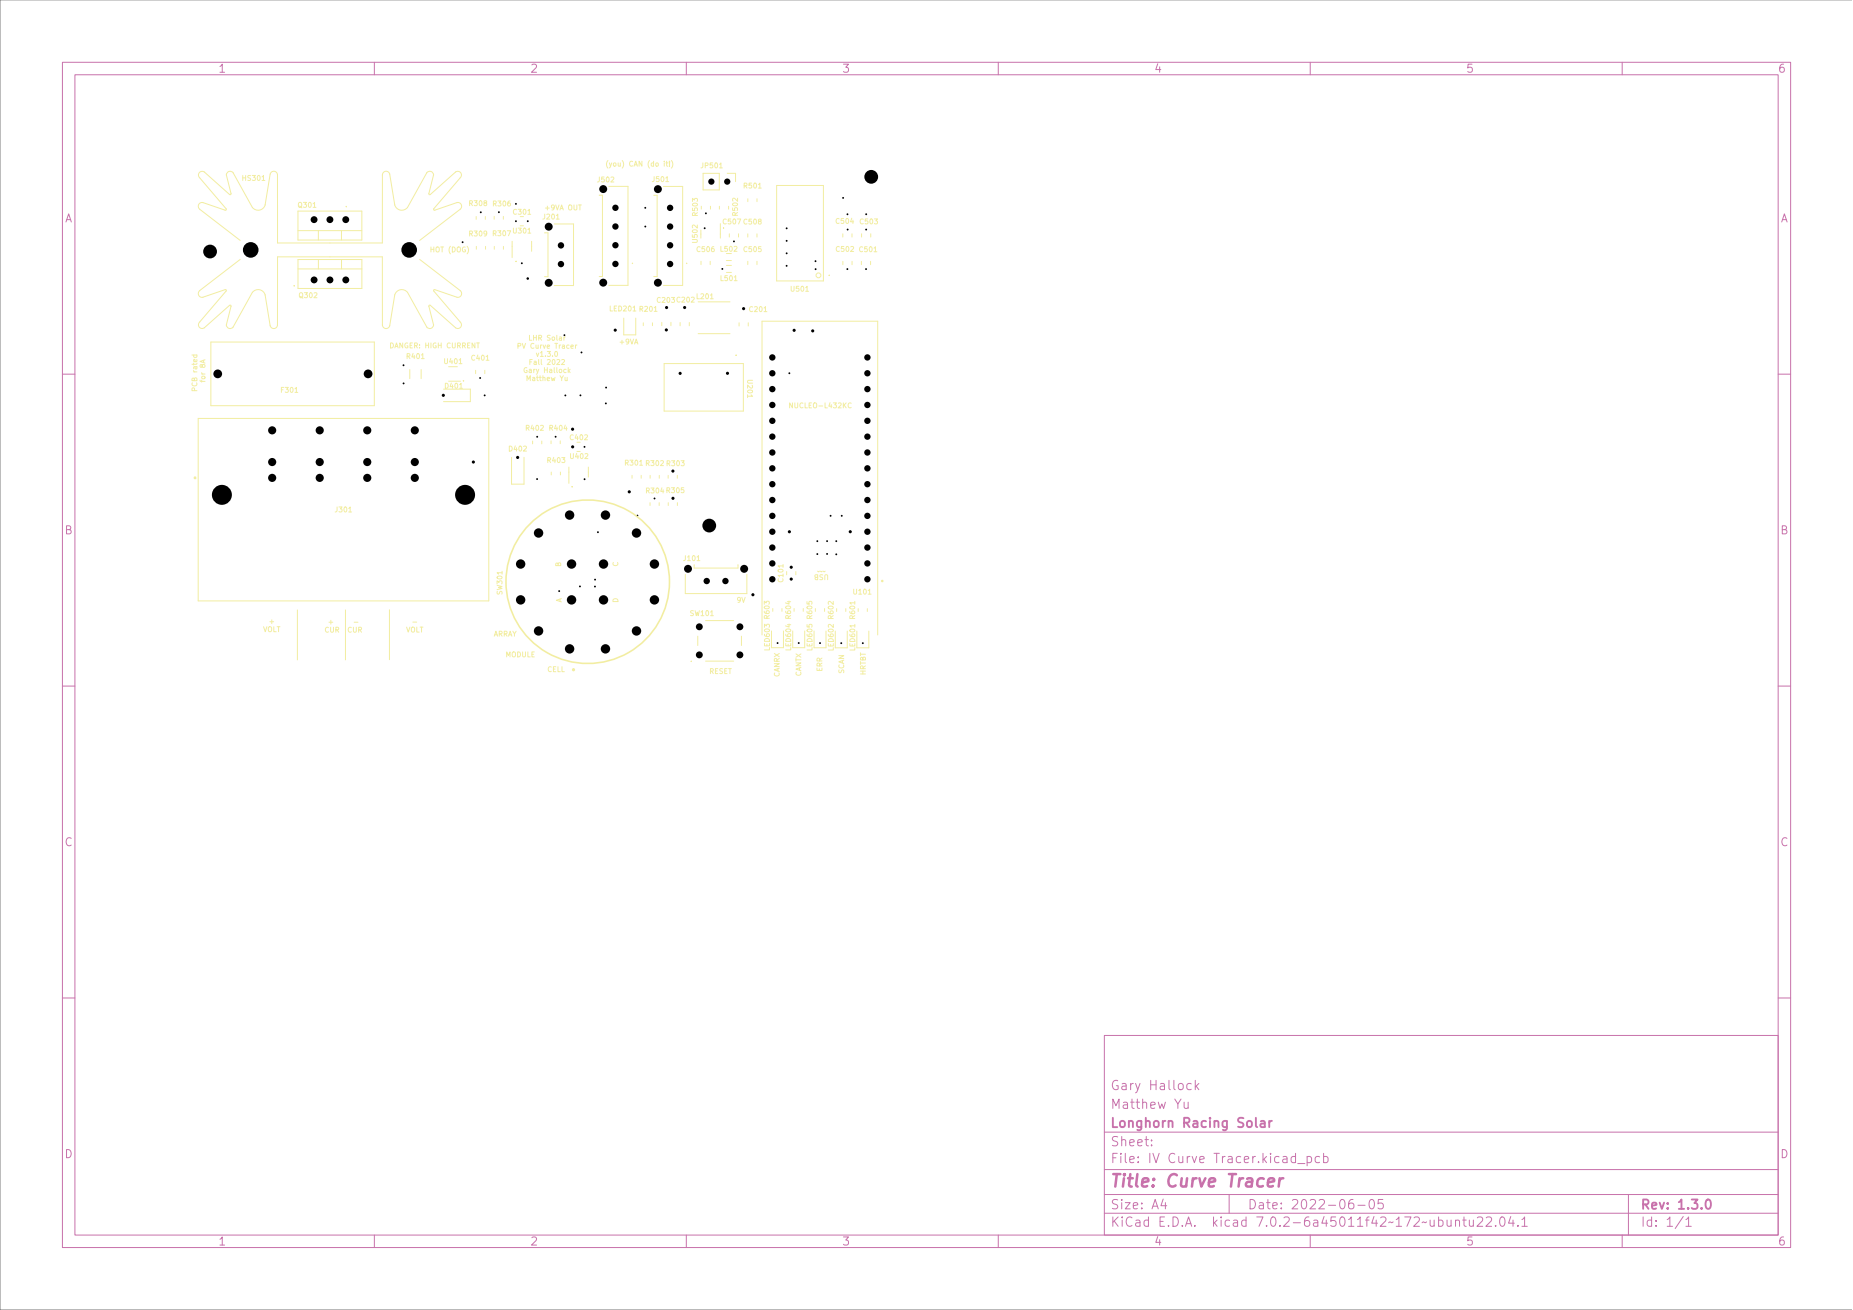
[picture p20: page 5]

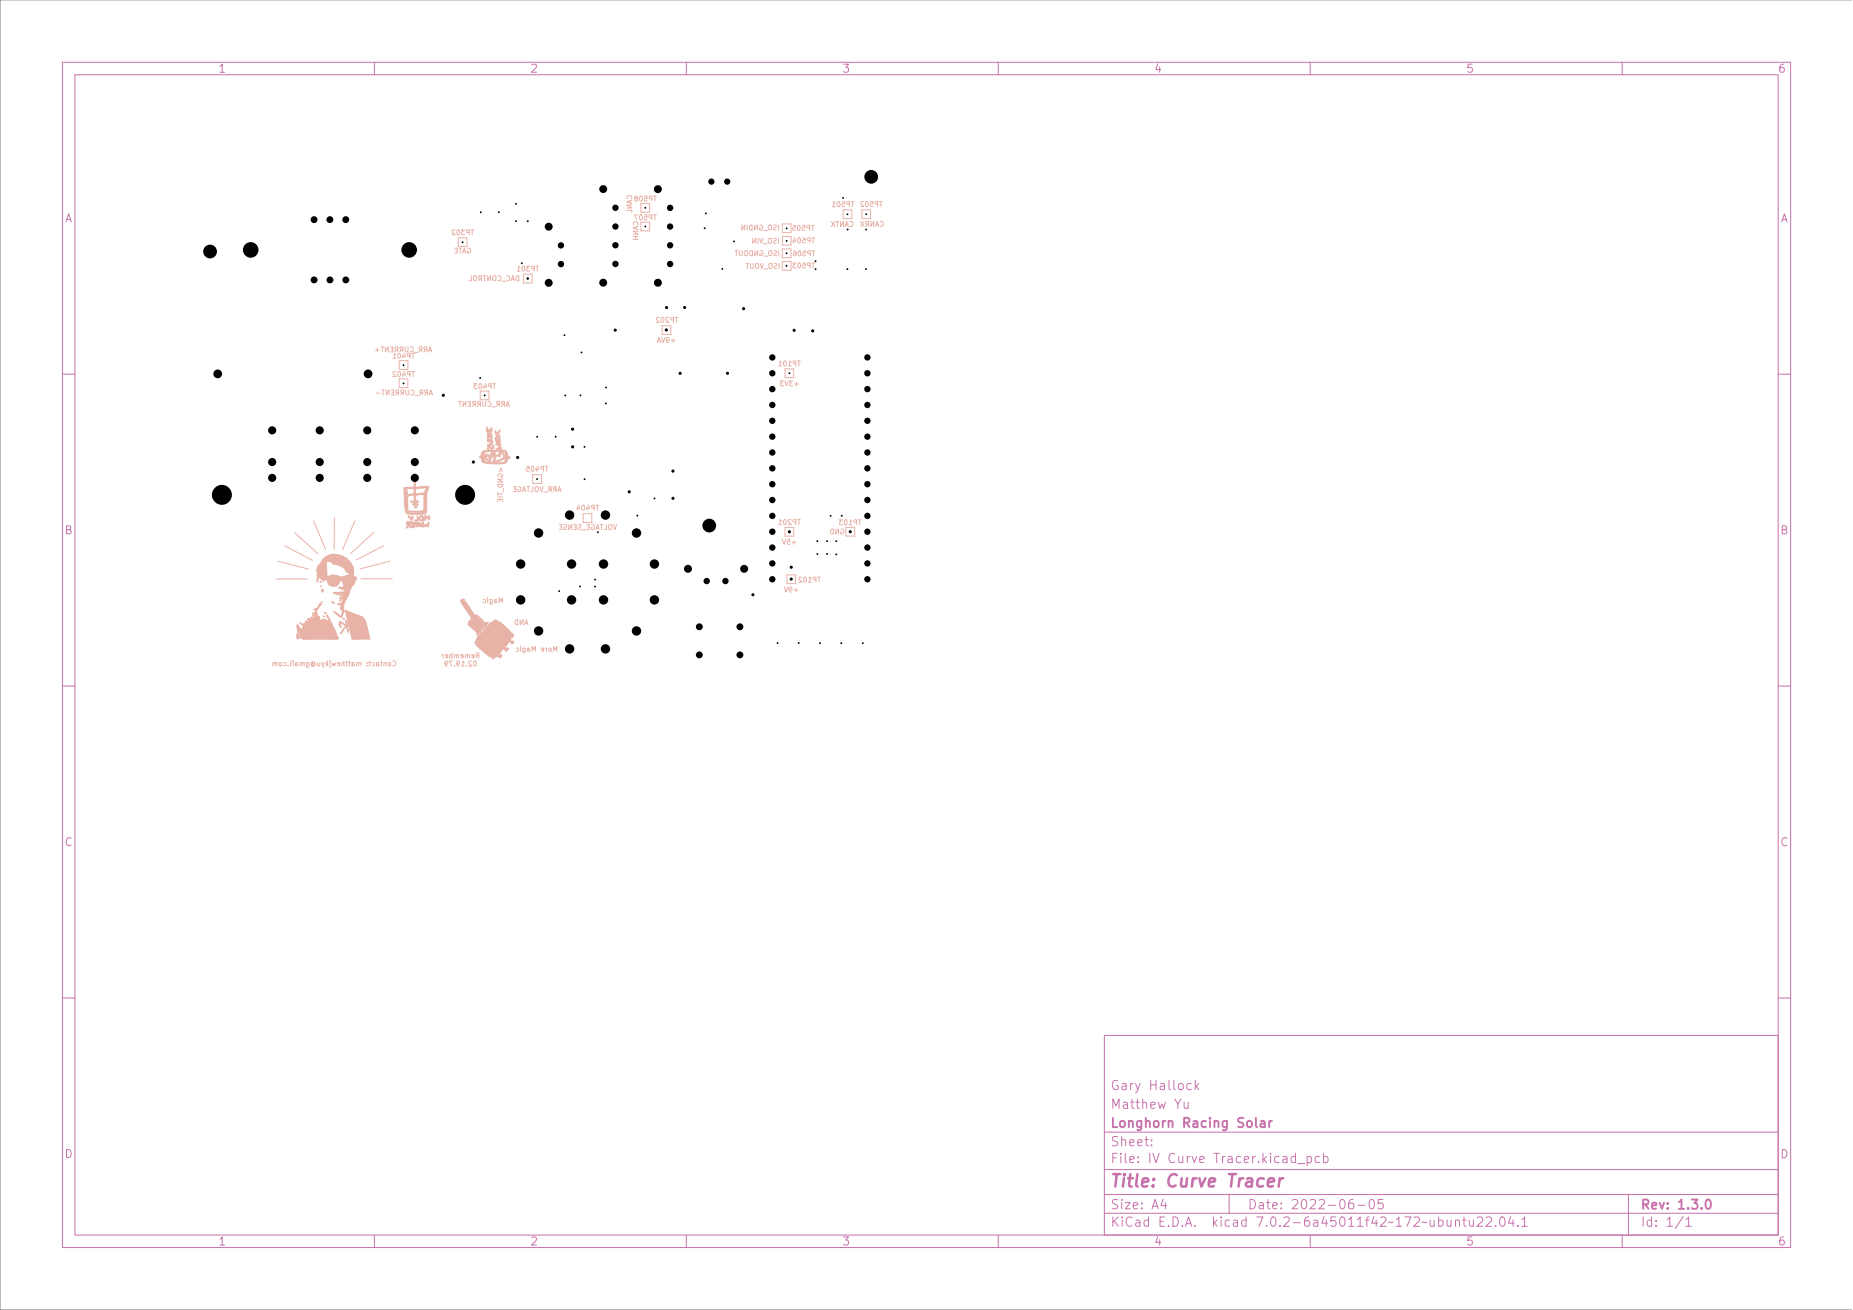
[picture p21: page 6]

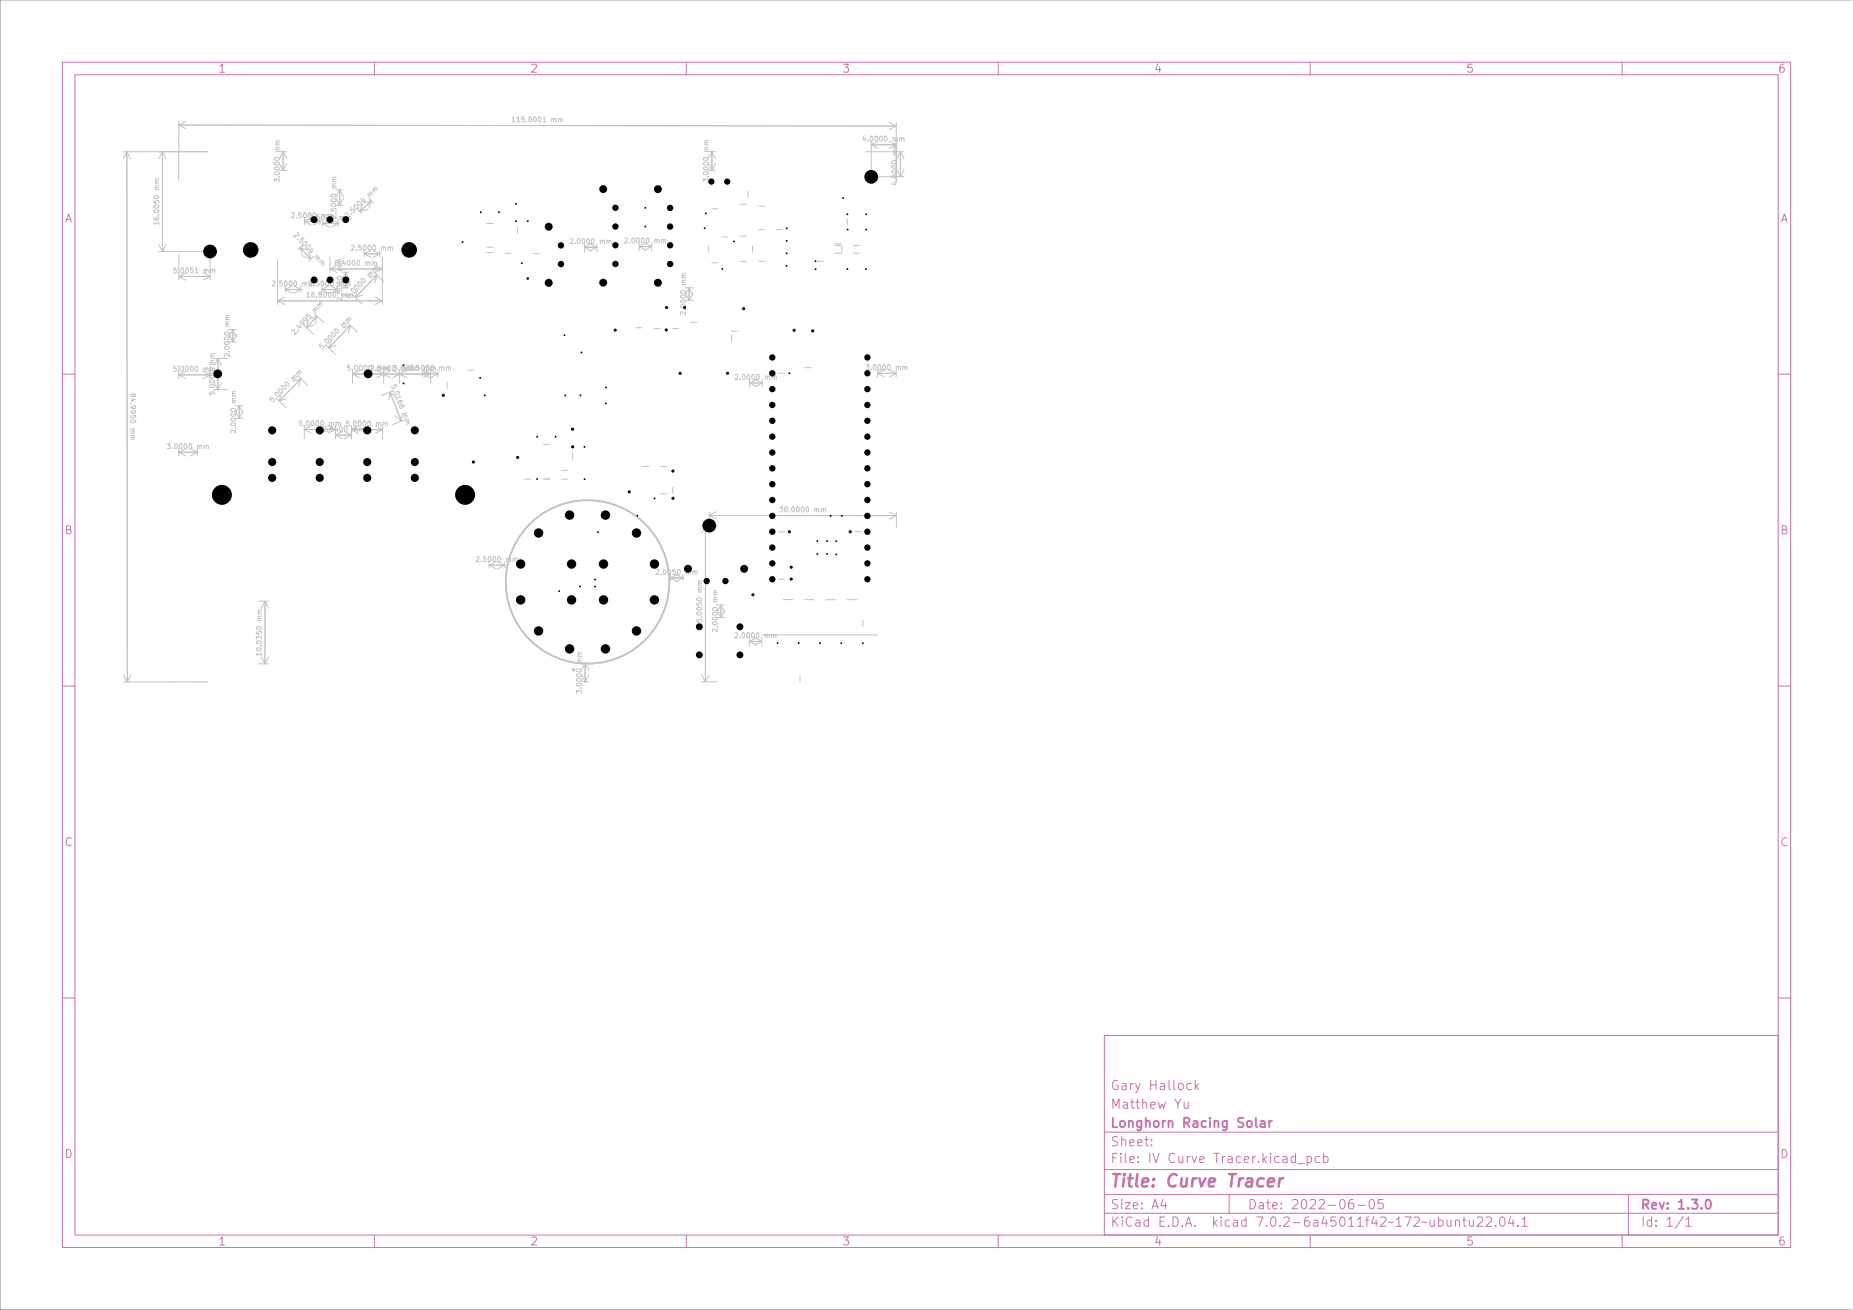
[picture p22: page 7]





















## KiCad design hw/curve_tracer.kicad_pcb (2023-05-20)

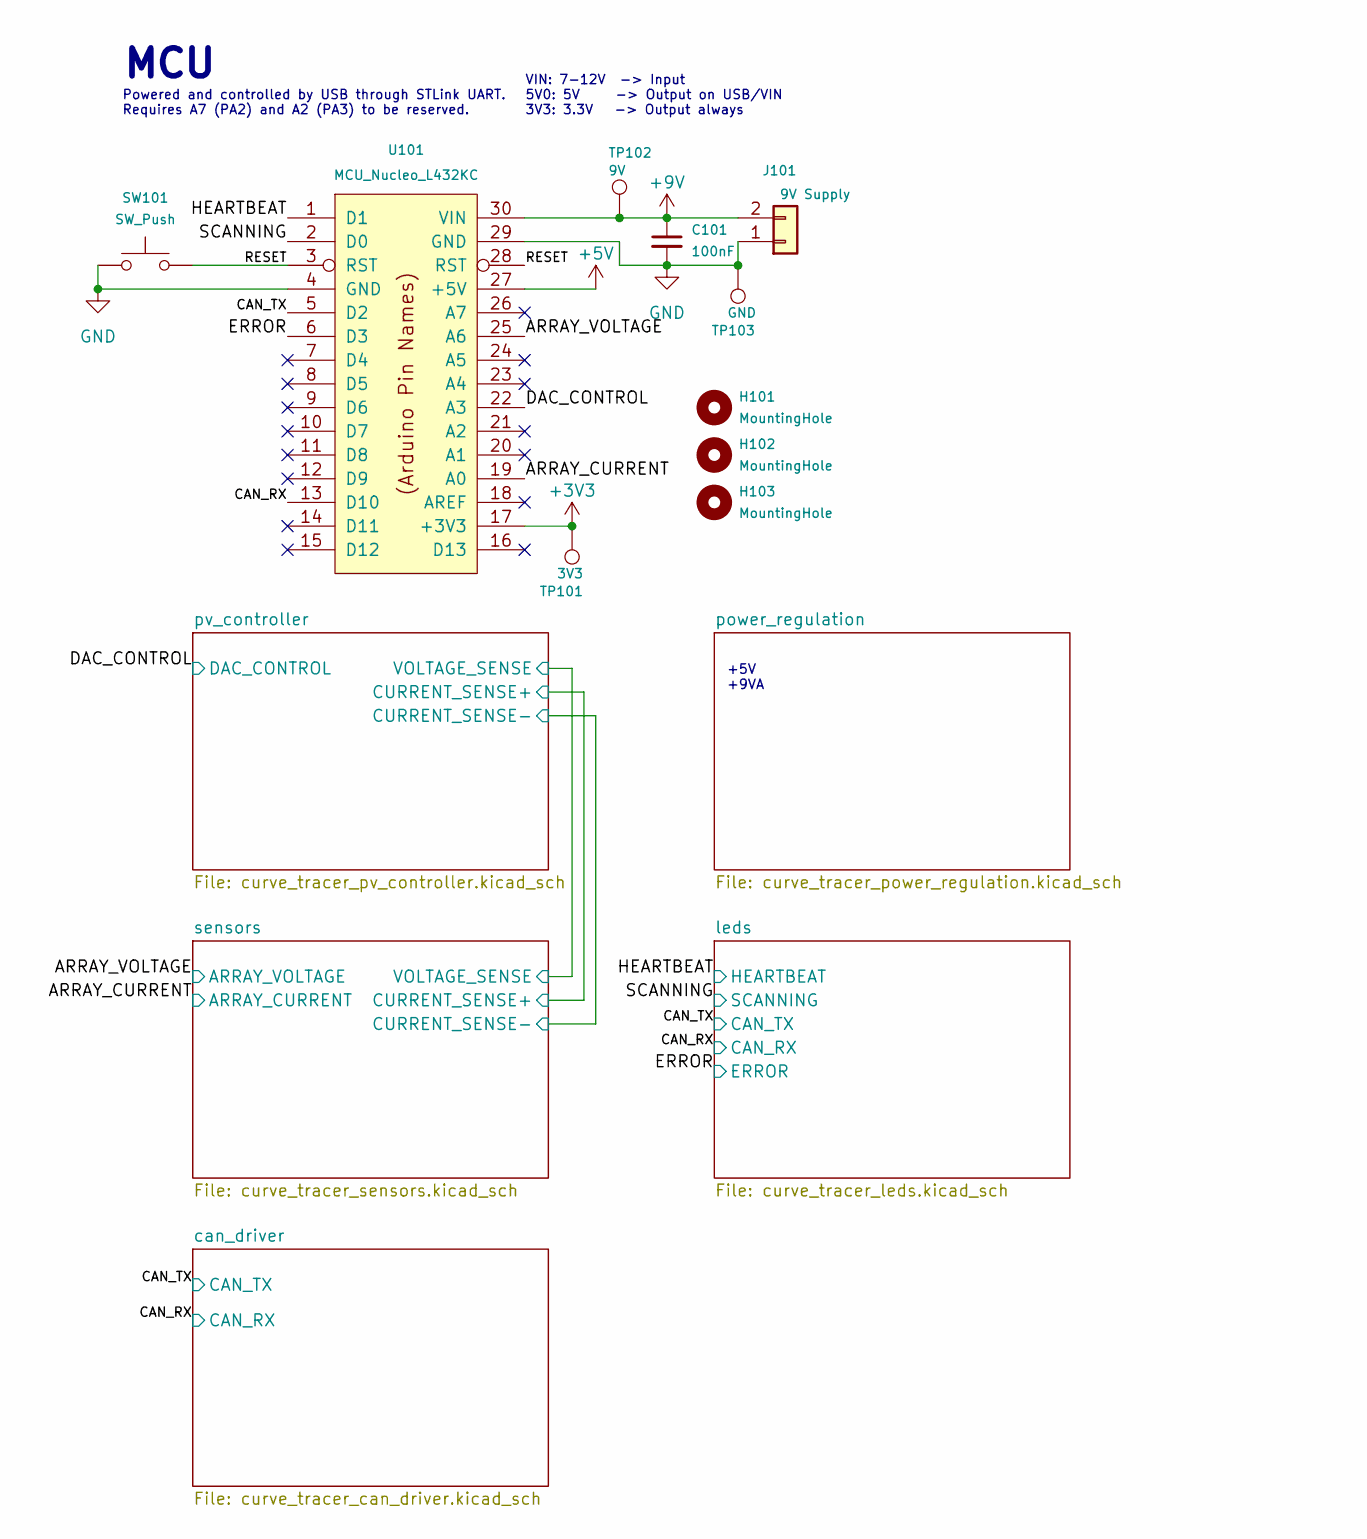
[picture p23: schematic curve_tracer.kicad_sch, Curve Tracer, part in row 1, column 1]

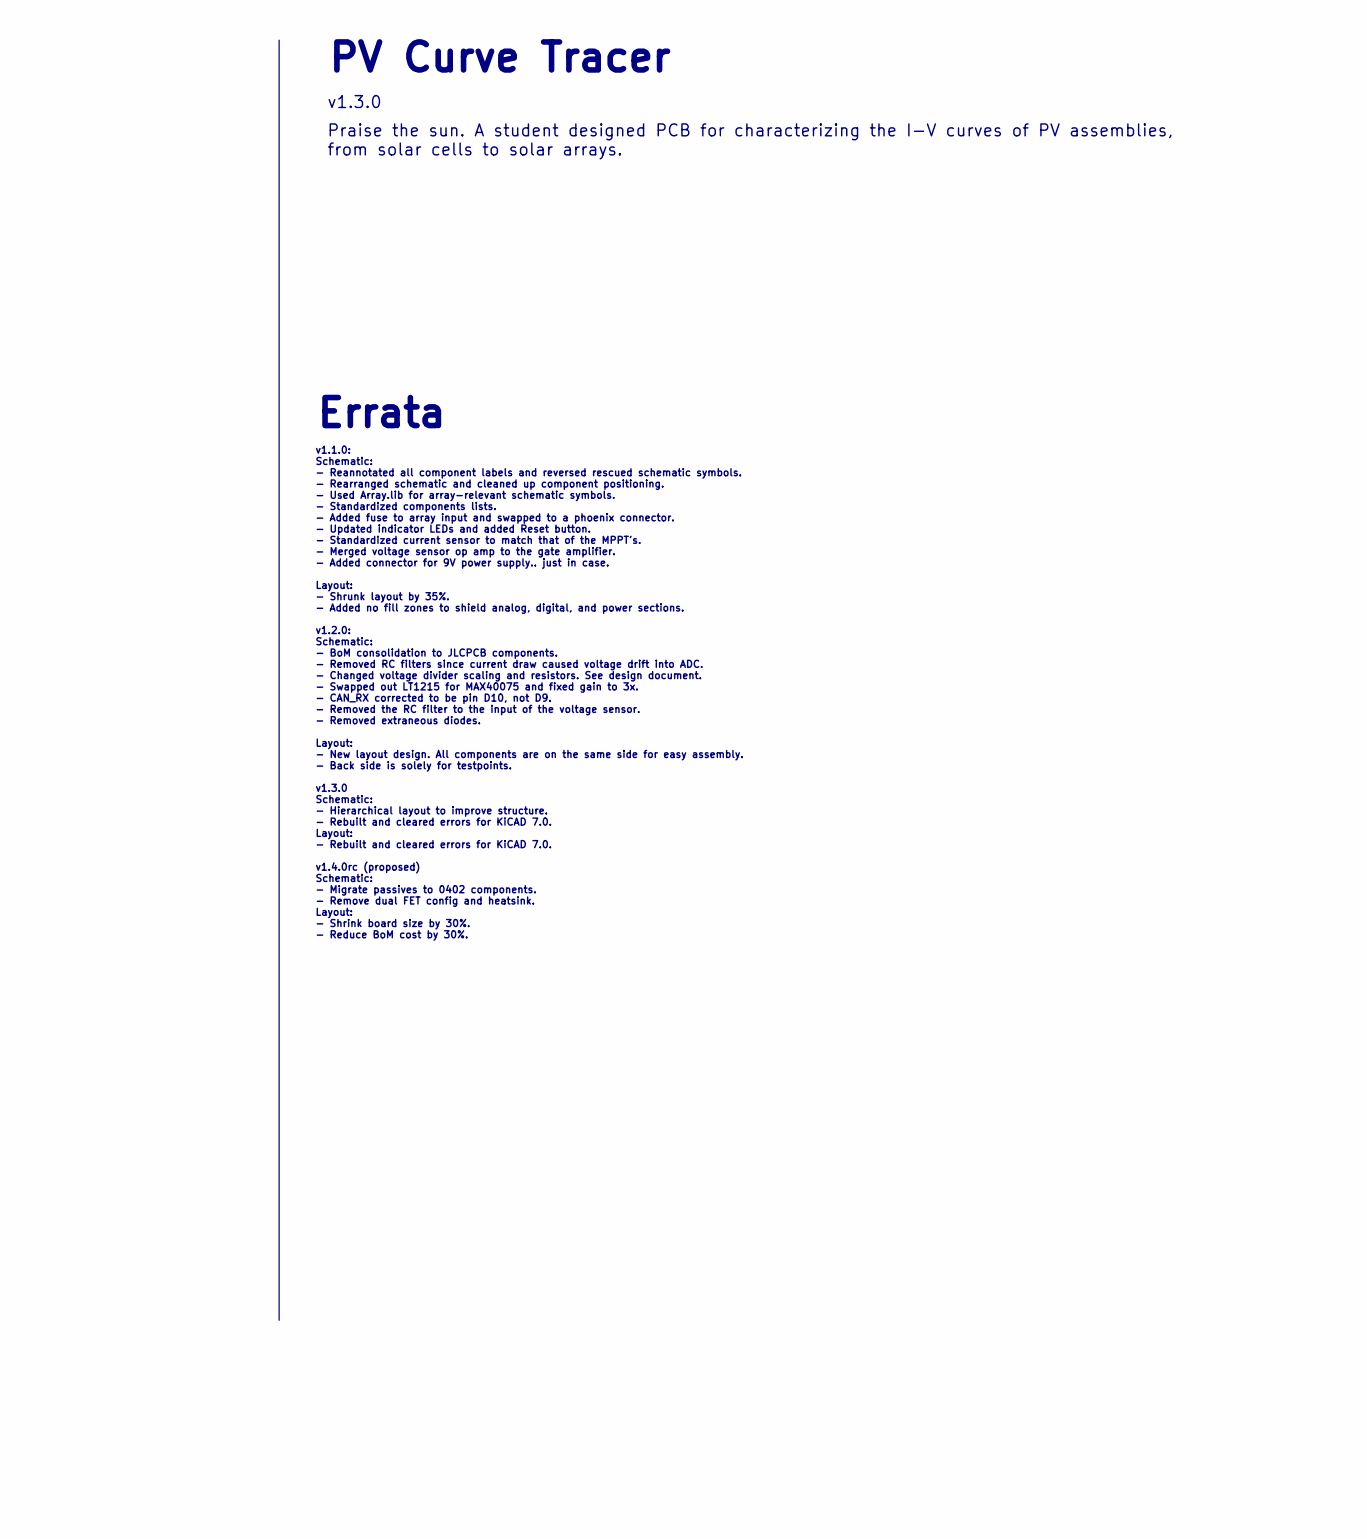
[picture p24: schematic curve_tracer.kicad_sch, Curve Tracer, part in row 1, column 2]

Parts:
C101: 100nF; C_0805_2012Metric; LCSC Part # C28233
H101, H102, H103: MountingHole; MountingHole_2.2mm_M2
J101: 9V Supply; Molex_Micro-Fit_3.0_43650-0215_1x02_P3.00mm_Vertical
SW101: SW_Push; SW_PUSH_6mm
TP101: 3V3; TestPoint_Pad_1.0x1.0mm
TP102: 9V; TestPoint_Pad_1.0x1.0mm
TP103: GND; TestPoint_Pad_1.0x1.0mm
U101: MCU_Nucleo_L432KC; MODULE_NUCLEO-L432KC

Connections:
+3V3: TP101.1, U101.17 (+3V3); also elsewhere on the board
+5V: U101.27 (+5V); also elsewhere on the board
+9V: C101.1, J101.2, TP102.1, U101.30 (VIN)
/ARRAY_CURRENT: U101.19 (A0); also elsewhere on the board
/ARRAY_VOLTAGE: U101.25 (A6); also elsewhere on the board
/CAN_RX: U101.13 (D10); also elsewhere on the board
/CAN_TX: U101.5 (D2); also elsewhere on the board
/DAC_CONTROL: U101.22 (A3); also elsewhere on the board
/ERROR: U101.6 (D3); also elsewhere on the board
/HEARTBEAT: U101.1 (D1); also elsewhere on the board
/RESET: SW101.2, U101.3 (RST), U101.28 (RST)
/SCANNING: U101.2 (D0); also elsewhere on the board
GND: C101.2, J101.1, SW101.1, TP103.1, U101.4 (GND), U101.29 (GND); also elsewhere on the board

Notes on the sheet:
Errata
Praise the sun. A student designed PCB for characterizing the I-V curves of PV assemblies, from solar cells to solar arrays.
PV Curve Tracer
+5V +9VA
MCU
Powered and controlled by USB through STLink UART. Requires A7 (PA2) and A2 (PA3) to be reserved.
v1.1.0: Schematic: - Reannotated all component labels and reversed rescued schematic symbols. - Rearranged schematic and cleaned up component positioning. - Used Array.lib for array-relevant schematic symbols. - Standardized components lists. - Added fuse to array input and swapped to a phoenix con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
v1.3.0
VIN: 7-12V -> Input 5V0: 5V -> Output on USB/VIN 3V3: 3.3V -> Output always

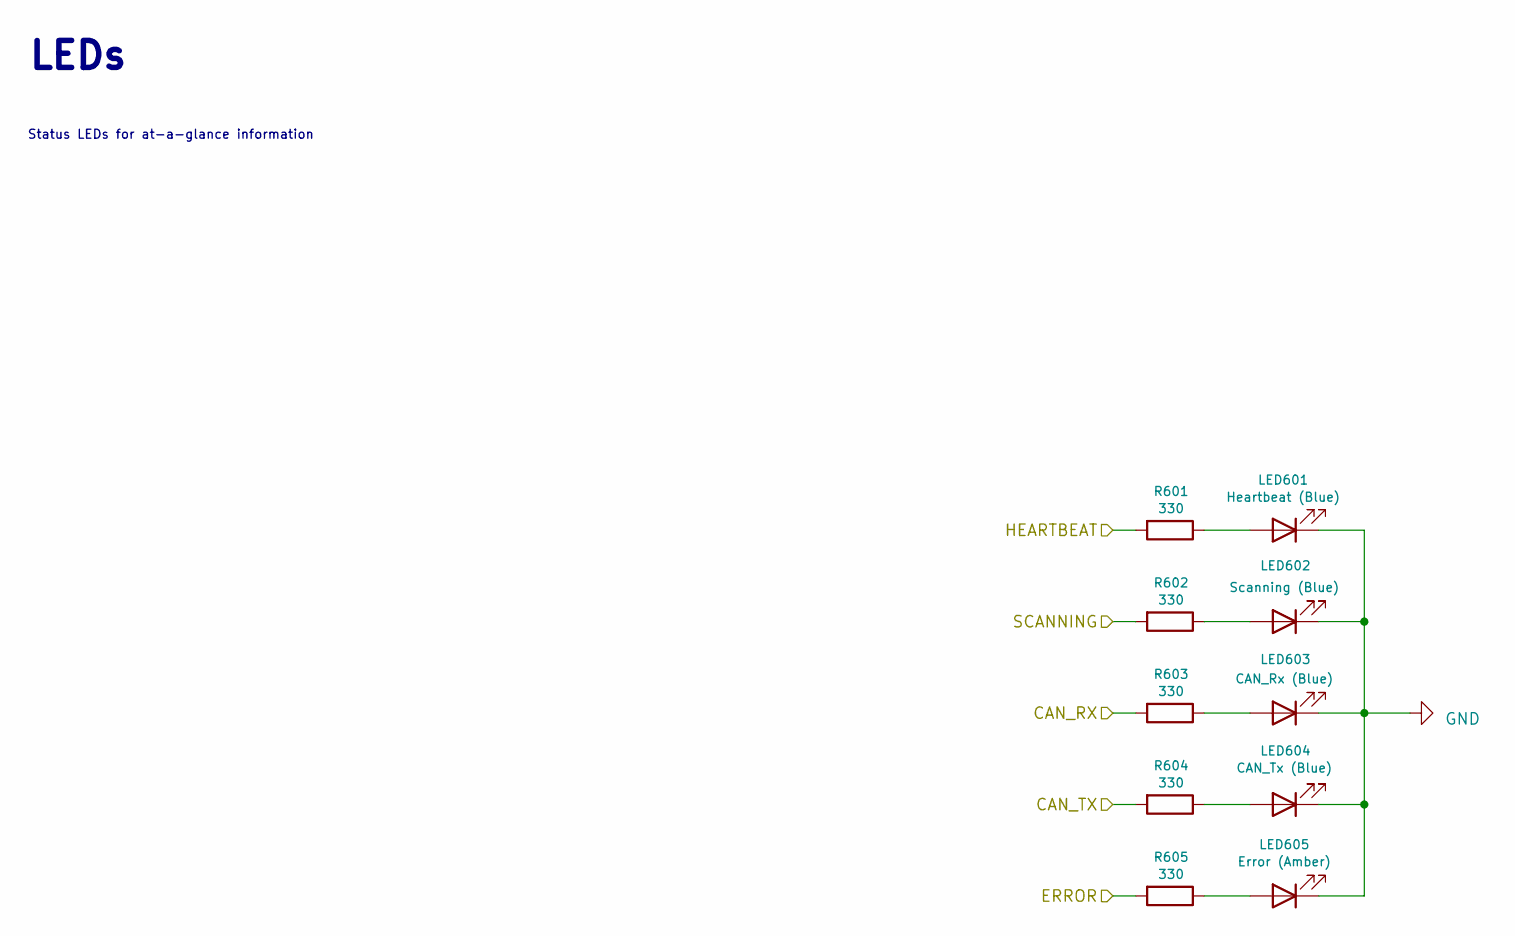
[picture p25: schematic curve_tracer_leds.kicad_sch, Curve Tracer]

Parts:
LED601: Heartbeat (Blue); LED_0805_2012Metric
LED602: Scanning (Blue); LED_0805_2012Metric
LED603: CAN_Rx (Blue); LED_0805_2012Metric
LED604: CAN_Tx (Blue); LED_0805_2012Metric
LED605: Error (Amber); LED_0805_2012Metric
R601, R602, R603, R604, R605: 330; R_0805_2012Metric; LCSC Part # C17630

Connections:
/CAN_RX: R603.2; also elsewhere on the board
/CAN_TX: R604.2; also elsewhere on the board
/ERROR: R605.2; also elsewhere on the board
/HEARTBEAT: R601.2; also elsewhere on the board
/SCANNING: R602.2; also elsewhere on the board
GND: LED601.1 (K), LED602.1 (K), LED603.1 (K), LED604.1 (K), LED605.1 (K); also elsewhere on the board
unnamed: LED601.2 (A), R601.1
unnamed: LED602.2 (A), R602.1
unnamed: LED603.2 (A), R603.1
unnamed: LED604.2 (A), R604.1
unnamed: LED605.2 (A), R605.1

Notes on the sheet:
Status LEDs for at-a-glance information
LEDs

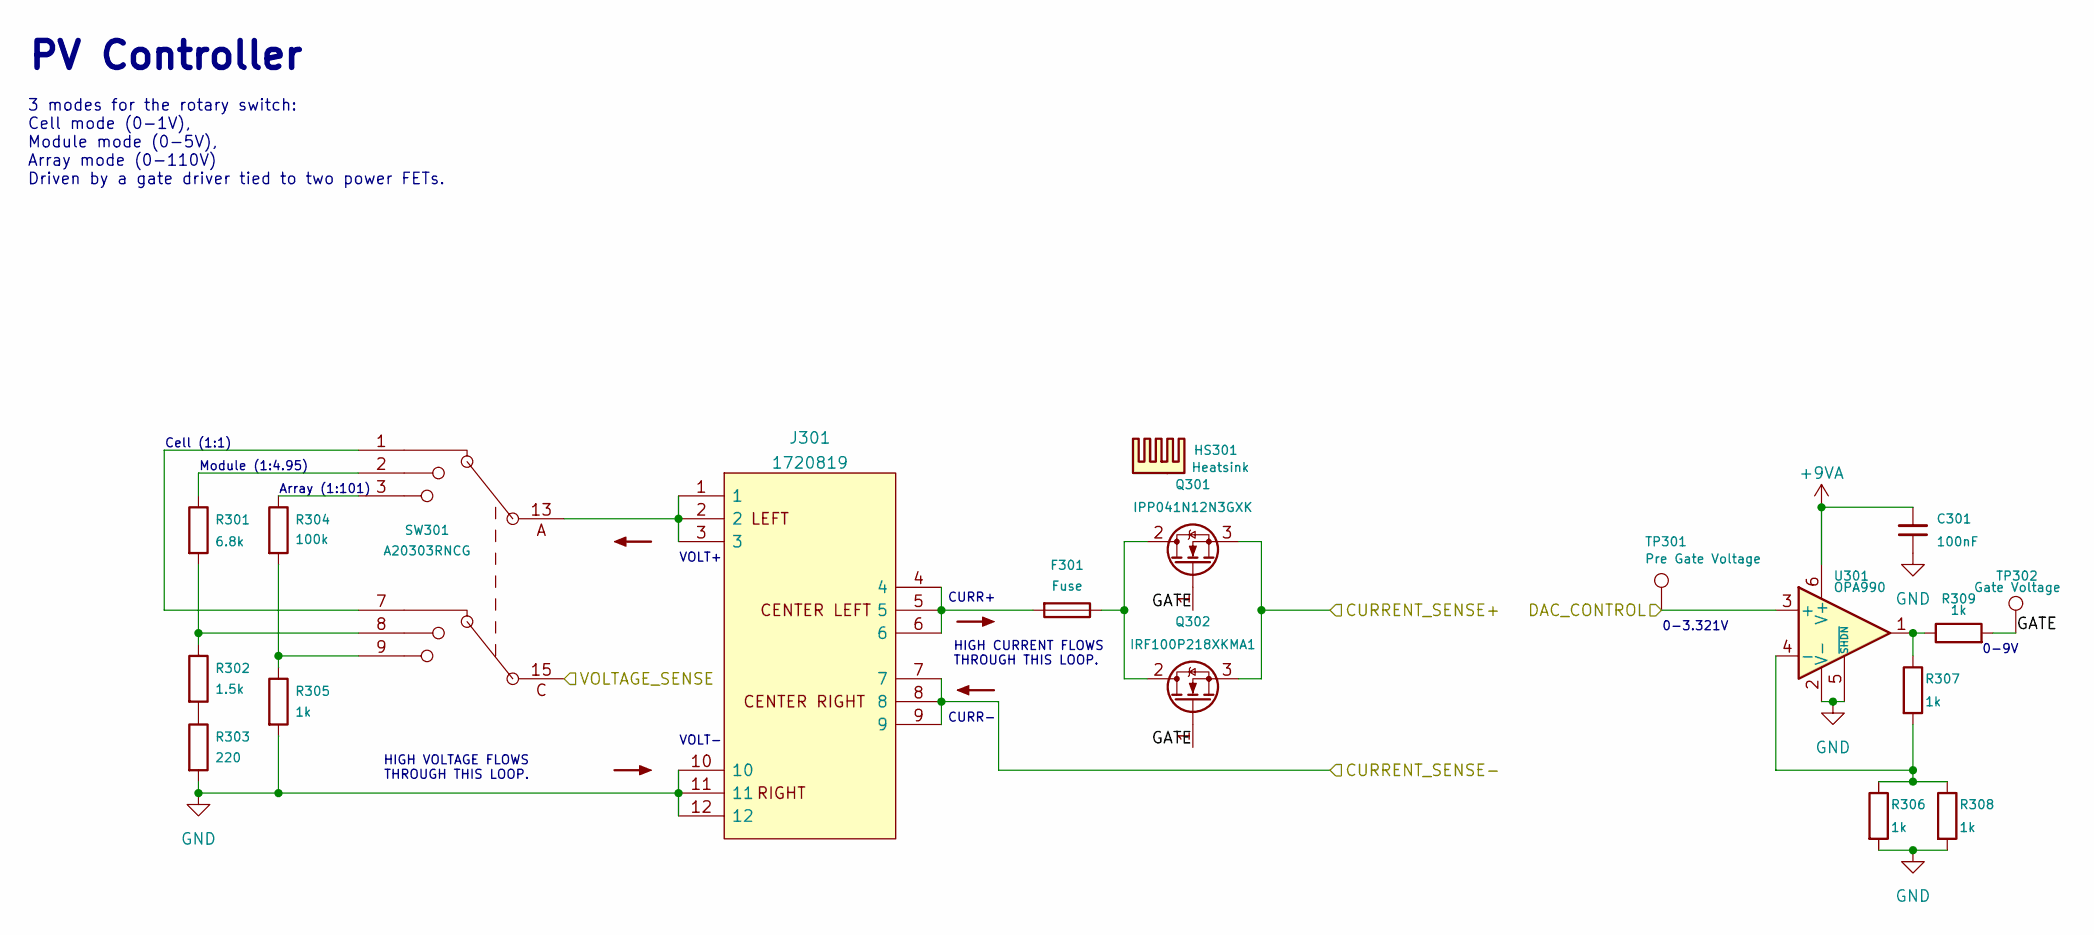
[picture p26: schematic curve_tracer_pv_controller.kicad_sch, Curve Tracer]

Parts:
C301: 100nF; C_0805_2012Metric; LCSC Part # C28233
F301: Fuse; 05200101Z_Fuze_Holder_5x20_PCB_Mount
HS301: Heatsink; Heatsink_Fischer_SK129-STS_42x25mm_2xDrill2.5mm
J301: 1720819
Q301: IPP041N12N3GXK; TO-220-3_Vertical
Q302: IRF100P218XKMA1; TO-220-3_Vertical
R301: 6.8k; R_0805_2012Metric; LCSC Part # C17772
R302: 1.5k; R_0805_2012Metric; LCSC Part # C4310
R303: 220; R_0805_2012Metric; LCSC Part # C17557
R304: 100k; R_0805_2012Metric; LCSC Part # C149504
R305, R306, R307, R308, R309: 1k; R_0805_2012Metric; LCSC Part # C17513
SW301: A20303RNCG; A20303RNCG_rotary_sw_dp3t
TP301: Pre Gate Voltage; TestPoint_Pad_1.0x1.0mm
TP302: Gate Voltage; TestPoint_Pad_1.0x1.0mm
U301: OPA990; SOT-23-6

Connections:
+9VA: C301.2, U301.6 (V+); also elsewhere on the board
/DAC_CONTROL: TP301.1, U301.3 (+); also elsewhere on the board
/pv_controller/CURRENT_SENSE+: Q301.3 (S), Q302.3 (S); also elsewhere on the board
/pv_controller/CURRENT_SENSE-: J301.7, J301.8, J301.9; also elsewhere on the board
/pv_controller/GATE: Q301.1 (G), Q302.1 (G), R309.2, TP302.1
/pv_controller/VOLTAGE_SENSE: SW301.15 (C); also elsewhere on the board
GND: C301.1, J301.10, J301.11, J301.12, R303.2, R305.2, R306.2, R308.2, U301.2 (V-), U301.5 (~SHDN); also elsewhere on the board
unnamed: F301.2, J301.4, J301.5, J301.6
unnamed: F301.1, Q301.2 (D), Q302.2 (D)
unnamed: R301.1, SW301.2
unnamed: R301.2, R302.1, SW301.8
unnamed: R302.2, R303.1
unnamed: R304.1, SW301.3
unnamed: R304.2, R305.1, SW301.9
unnamed: R307.1, R309.1, U301.1
unnamed: J301.1, J301.2, J301.3, SW301.13 (A)
unnamed: SW301.1, SW301.7
unnamed: R306.1, R307.2, R308.1, U301.4 (-)

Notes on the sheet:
PV Controller
VOLT+
0-3.321V
HIGH CURRENT FLOWS THROUGH THIS LOOP.
3 modes for the rotary switch: Cell mode (0-1V), Module mode (0-5V), Array mode (0-110V) Driven by a gate driver tied to two power FETs.
CURR+
Module (1:4.95)
0-9V
CURR-
HIGH VOLTAGE FLOWS THROUGH THIS LOOP.
Cell (1:1)
Array (1:101)
VOLT-

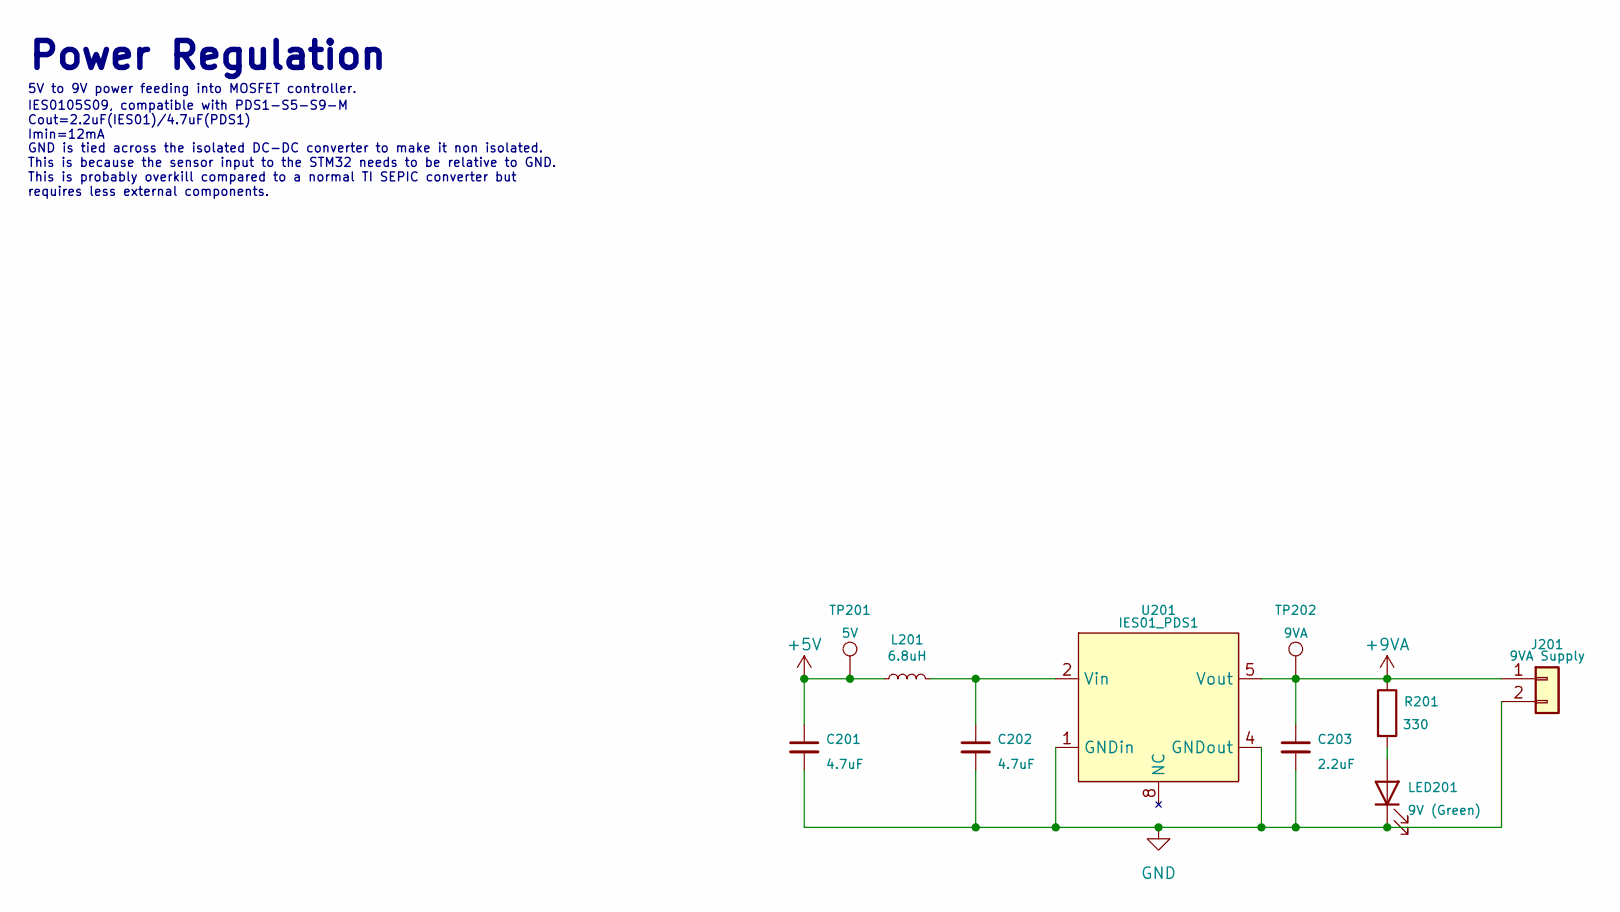
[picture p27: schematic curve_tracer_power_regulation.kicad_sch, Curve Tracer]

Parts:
C201, C202: 4.7uF; C_0805_2012Metric; LCSC Part # C1779
C203: 2.2uF; C_0805_2012Metric; LCSC Part # C49217
J201: 9VA Supply; Molex_Micro-Fit_3.0_43650-0215_1x02_P3.00mm_Vertical
L201: 6.8uH; L_Taiyo-Yuden_NR-50xx
LED201: 9V (Green); LED_0805_2012Metric
R201: 330; R_0805_2012Metric; LCSC Part # C17630
TP201: 5V; TestPoint_Pad_1.0x1.0mm
TP202: 9VA; TestPoint_Pad_1.0x1.0mm
U201: IES01_PDS1

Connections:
+5V: C201.1, L201.1, TP201.1; also elsewhere on the board
+9VA: C203.1, J201.1, R201.1, TP202.1, U201.5 (Vout); also elsewhere on the board
GND: C201.2, C202.2, C203.2, J201.2, LED201.1 (K), U201.1 (GNDin), U201.4 (GNDout); also elsewhere on the board
unnamed: LED201.2 (A), R201.2
unnamed: C202.1, L201.2, U201.2 (Vin)

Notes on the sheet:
GND is tied across the isolated DC-DC converter to make it non isolated. This is because the sensor input to the STM32 needs to be relative to GND. This is probably overkill compared to a normal TI SEPIC converter but requires less external components.
IES0105S09, compatible with PDS1-S5-S9-M Cout=2.2uF(IES01)/4.7uF(PDS1) Imin=12mA
Power Regulation
5V to 9V power feeding into MOSFET controller.

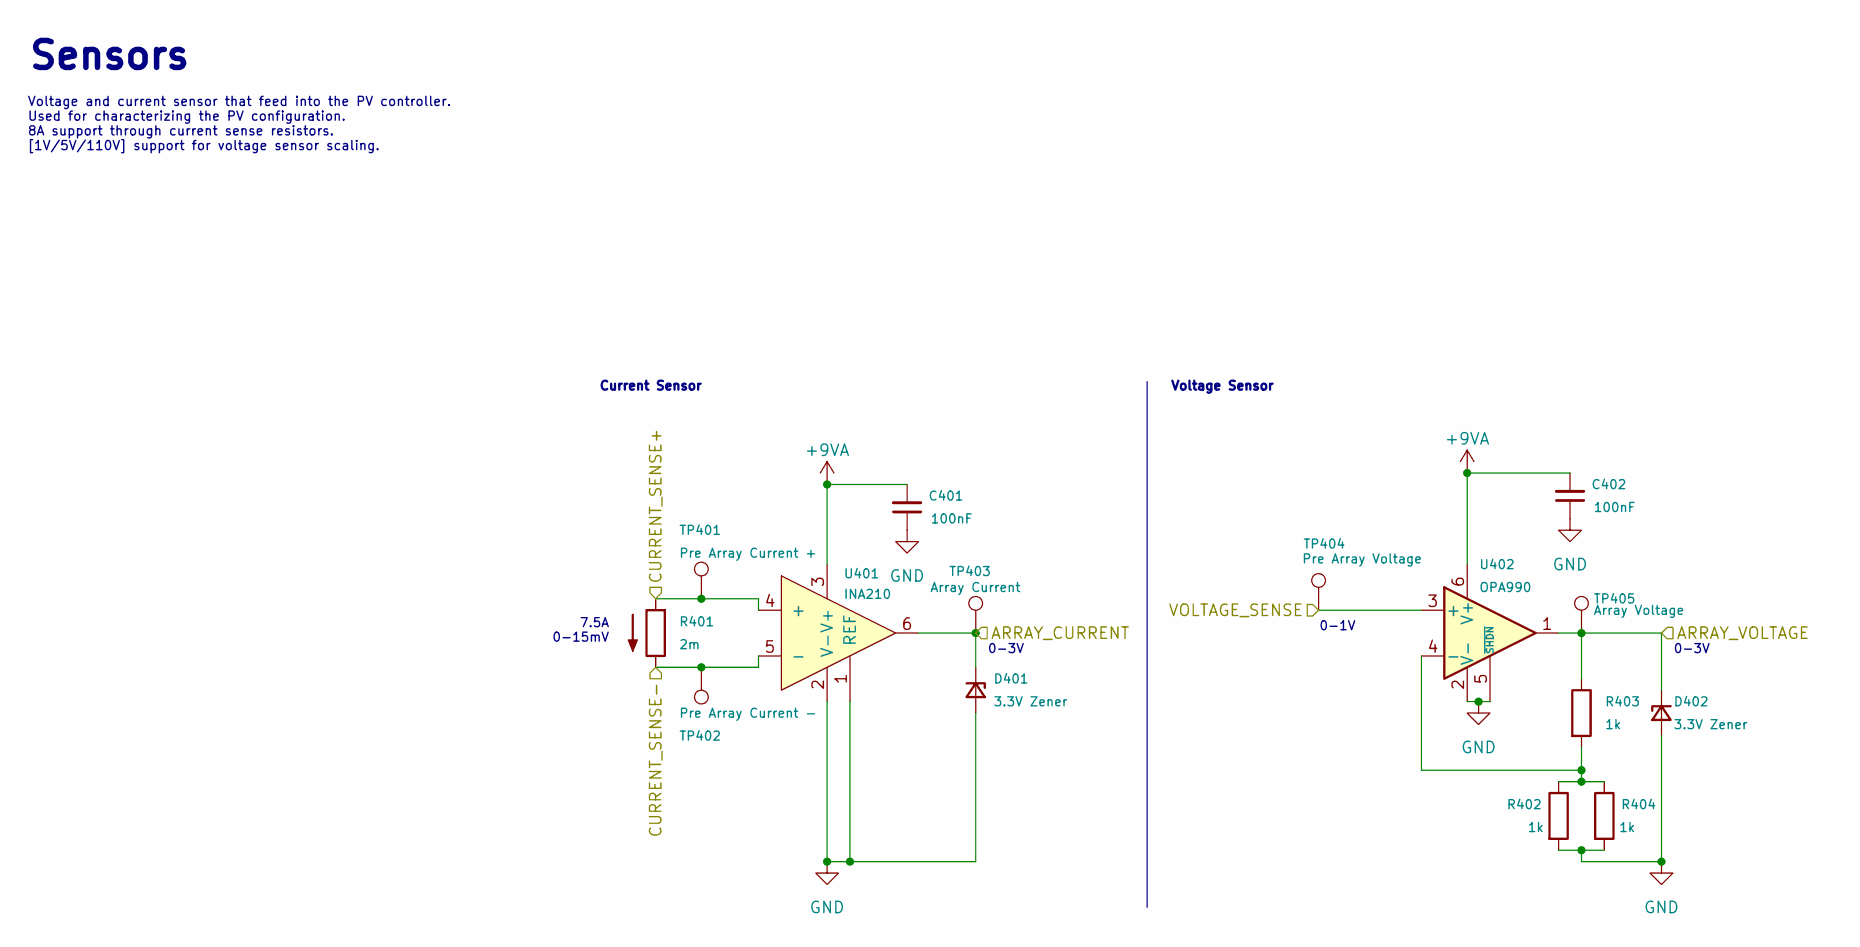
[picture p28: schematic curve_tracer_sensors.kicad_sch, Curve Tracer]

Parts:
C401, C402: 100nF; C_0805_2012Metric; LCSC Part # C28233
D401, D402: 3.3V Zener; D_MiniMELF; LCSC Part # C8056
R401: 2m; R_1206_3216Metric
R402, R403, R404: 1k; R_0805_2012Metric; LCSC Part # C17513
TP401: Pre Array Current +; TestPoint_Pad_1.0x1.0mm
TP402: Pre Array Current -; TestPoint_Pad_1.0x1.0mm
TP403: Array Current; TestPoint_Pad_1.0x1.0mm
TP404: Pre Array Voltage; TestPoint_Pad_1.0x1.0mm
TP405: Array Voltage; TestPoint_Pad_1.0x1.0mm
U401: INA210; SOT-363_SC-70-6_Handsoldering
U402: OPA990; SOT-23-6

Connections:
+9VA: C401.2, C402.2, U401.3 (V+), U402.6 (V+); also elsewhere on the board
/ARRAY_CURRENT: D401.1 (K), TP403.1, U401.6; also elsewhere on the board
/ARRAY_VOLTAGE: D402.1 (K), R403.1, TP405.1, U402.1; also elsewhere on the board
/pv_controller/CURRENT_SENSE+: R401.2, TP401.1, U401.4 (+); also elsewhere on the board
/pv_controller/CURRENT_SENSE-: R401.1, TP402.1, U401.5 (-); also elsewhere on the board
/pv_controller/VOLTAGE_SENSE: TP404.1, U402.3 (+); also elsewhere on the board
GND: C401.1, C402.1, D401.2 (A), D402.2 (A), R402.2, R404.2, U401.1 (REF), U401.2 (V-), U402.2 (V-), U402.5 (~SHDN); also elsewhere on the board
unnamed: R402.1, R403.2, R404.1, U402.4 (-)

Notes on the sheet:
0-3V
Sensors
Voltage and current sensor that feed into the PV controller. Used for characterizing the PV configuration. 8A support through current sense resistors. [1V/5V/110V] support for voltage sensor scaling.
Voltage Sensor
0-1V
7.5A 0-15mV
Current Sensor

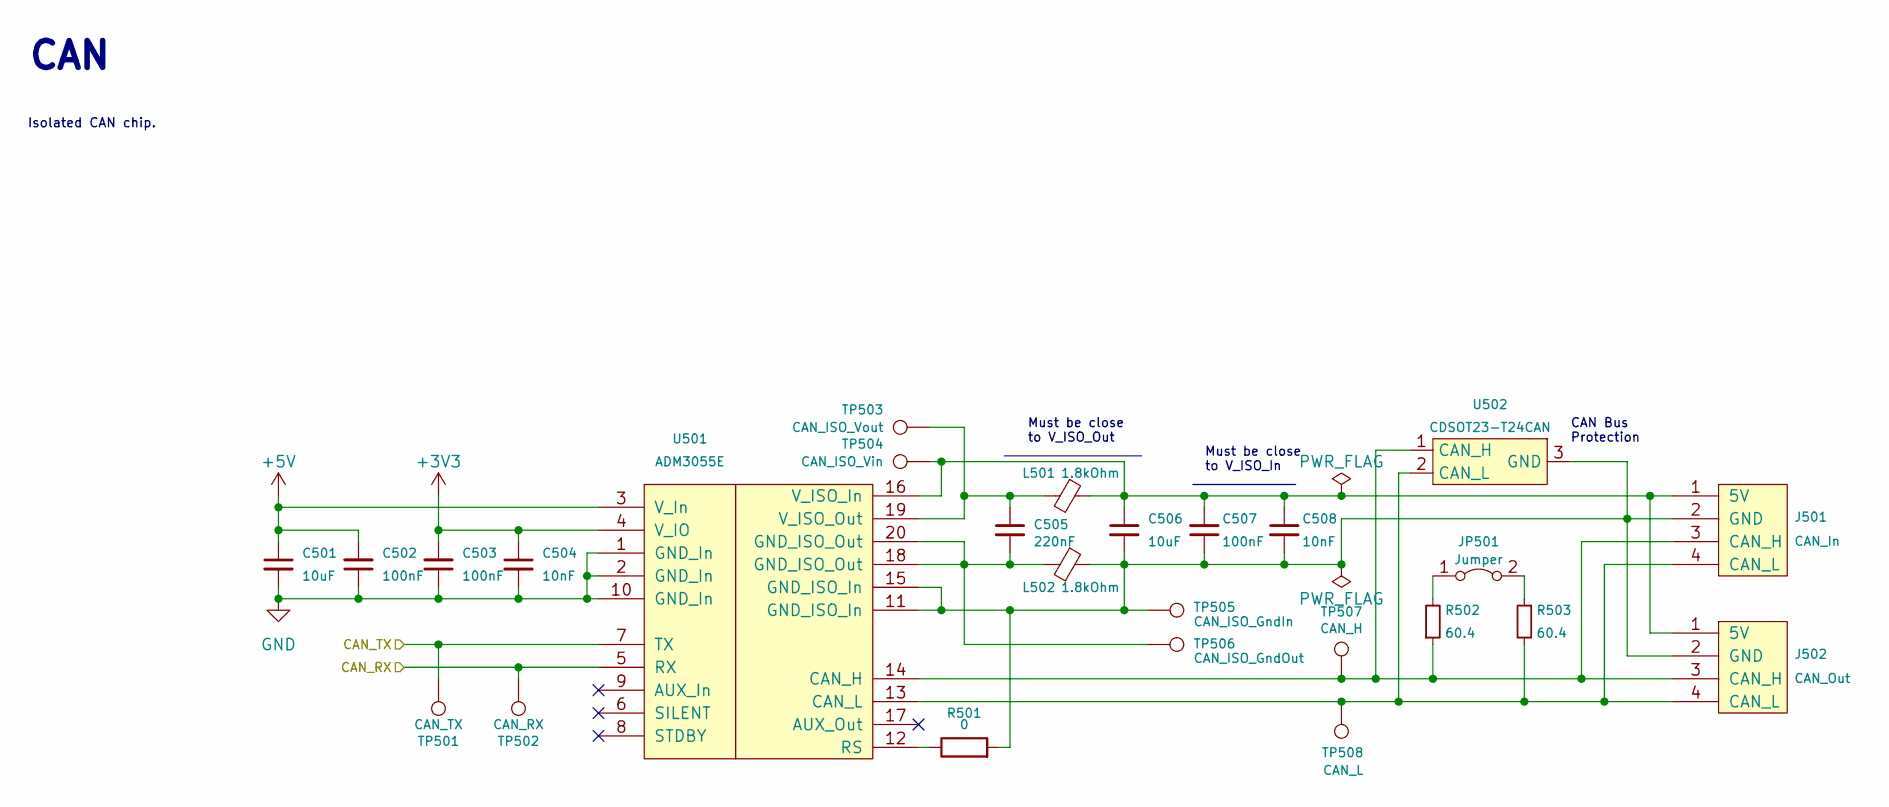
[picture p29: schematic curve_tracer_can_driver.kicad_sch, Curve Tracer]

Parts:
C501, C506: 10uF; C_0805_2012Metric; LCSC Part # C15850
C502, C503, C507: 100nF; C_0805_2012Metric; LCSC Part # C28233
C504, C508: 10nF; C_0805_2012Metric; LCSC Part # C1710
C505: 220nF; C_0805_2012Metric; LCSC Part # C5378
J501: CAN_In; Molex_Micro-Fit_3.0_43650-0415_1x04_P3.00mm_Vertical
J502: CAN_Out; Molex_Micro-Fit_3.0_43650-0415_1x04_P3.00mm_Vertical
JP501: Jumper; PinHeader_1x02_P2.54mm_Vertical
L501, L502: 1.8kOhm; L_0805_2012Metric
R501: 0; R_0805_2012Metric; LCSC Part # C17477
R502, R503: 60.4; R_0805_2012Metric
TP501: CAN_TX; TestPoint_Pad_1.0x1.0mm
TP502: CAN_RX; TestPoint_Pad_1.0x1.0mm
TP503: CAN_ISO_Vout; TestPoint_Pad_1.0x1.0mm
TP504: CAN_ISO_Vin; TestPoint_Pad_1.0x1.0mm
TP505: CAN_ISO_GndIn; TestPoint_Pad_1.0x1.0mm
TP506: CAN_ISO_GndOut; TestPoint_Pad_1.0x1.0mm
TP507: CAN_H; TestPoint_Pad_1.0x1.0mm
TP508: CAN_L; TestPoint_Pad_1.0x1.0mm
U501: ADM3055E; ADM3055EBRIZ
U502: CDSOT23-T24CAN; SOT-23

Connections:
+3V3: C503.2, C504.1, U501.4 (V_IO); also elsewhere on the board
+5V: C501.1, C502.2, U501.3 (V_In); also elsewhere on the board
/CAN_RX: TP502.1, U501.5 (RX); also elsewhere on the board
/CAN_TX: TP501.1, U501.7 (TX); also elsewhere on the board
GND: C501.2, C502.1, C503.1, C504.2, U501.1 (GND_In), U501.2 (GND_In), U501.10 (GND_In); also elsewhere on the board
unnamed: C505.2, L502.2, TP506.1, U501.18 (GND_ISO_Out), U501.20 (GND_ISO_Out)
unnamed: C506.1, C507.2, C508.1, J501.1 (5V), J502.1 (5V), L501.1, TP504.1, U501.16 (V_ISO_In)
unnamed: J501.3 (CAN_H), J502.3 (CAN_H), R502.1, TP507.1, U501.14 (CAN_H), U502.1 (CAN_H)
unnamed: J501.4 (CAN_L), J502.4 (CAN_L), R503.2, TP508.1, U501.13 (CAN_L), U502.2 (CAN_L)
unnamed: C506.2, C507.1, C508.2, J501.2 (GND), J502.2 (GND), L502.1, R501.2, TP505.1, U501.11 (GND_ISO_In), U501.15 (GND_ISO_In), U502.3 (GND)
unnamed: JP501.1 (A), R502.2
unnamed: JP501.2 (B), R503.1
unnamed: R501.1, U501.12 (RS)
unnamed: C505.1, L501.2, TP503.1, U501.19 (V_ISO_Out)

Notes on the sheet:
CAN Bus Protection
CAN
Must be close to V_ISO_Out
Isolated CAN chip.
Must be close to V_ISO_In

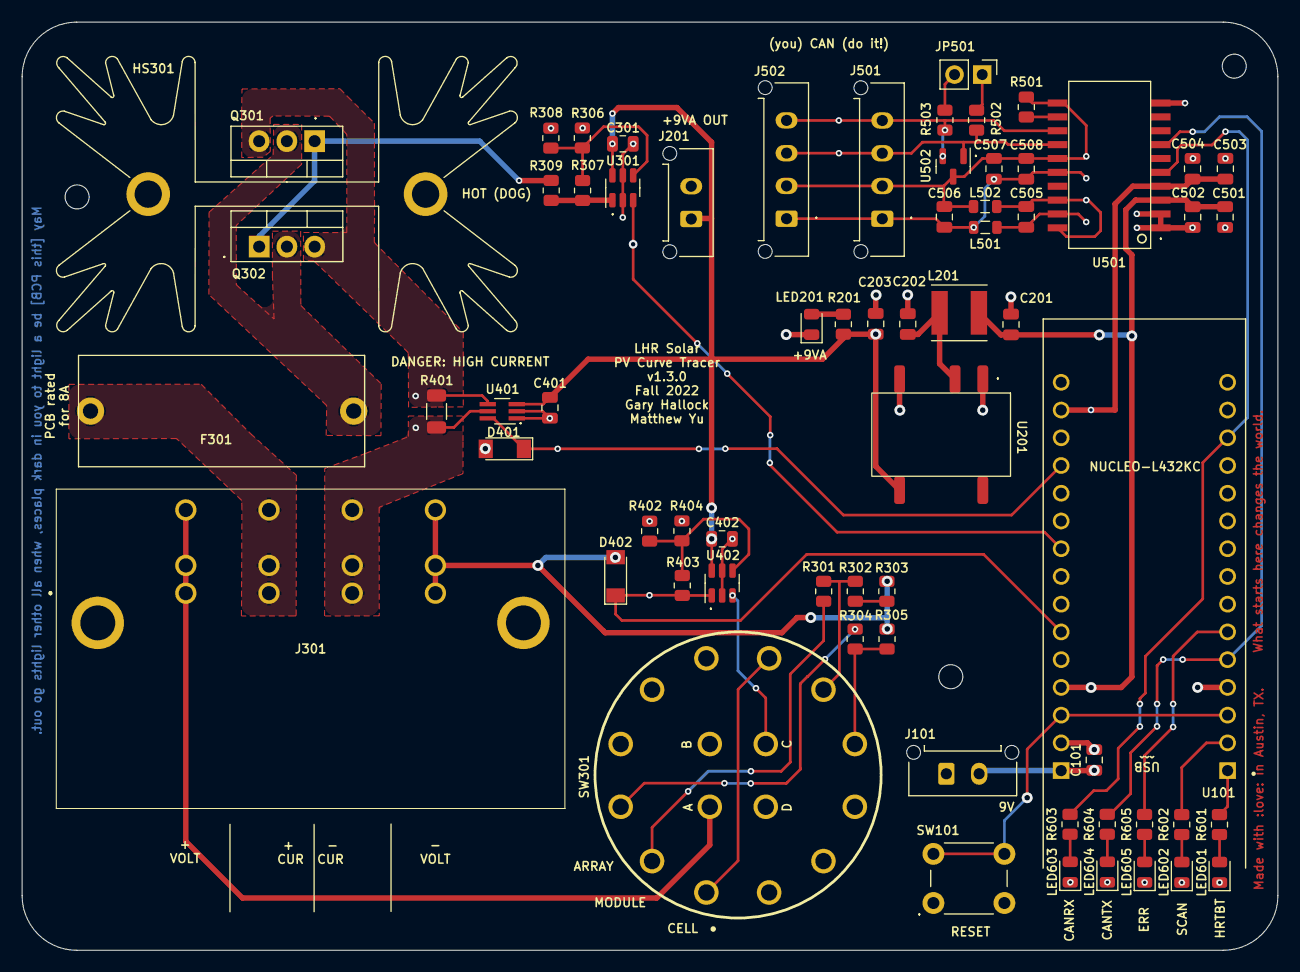
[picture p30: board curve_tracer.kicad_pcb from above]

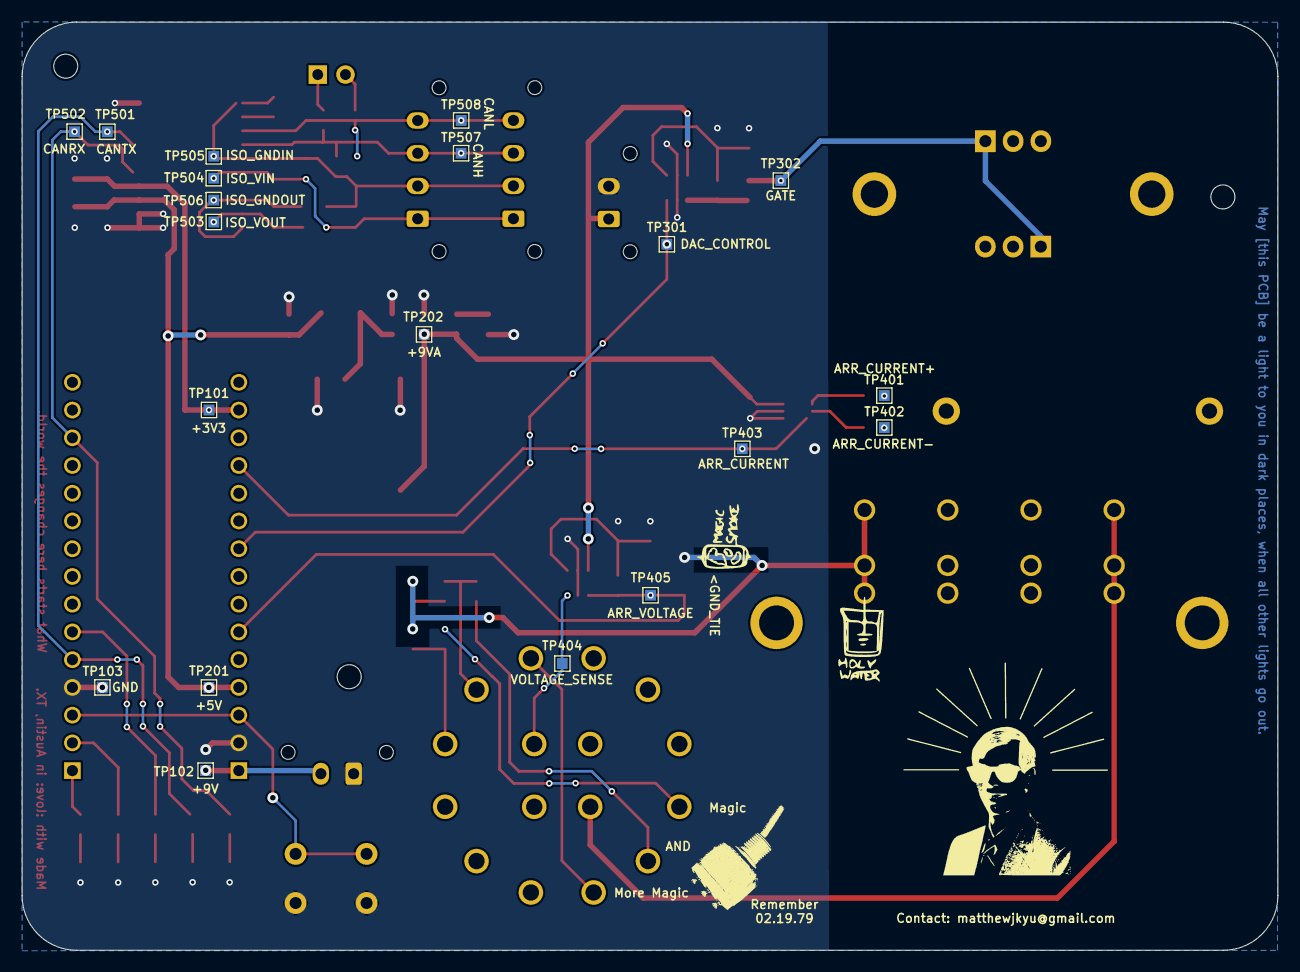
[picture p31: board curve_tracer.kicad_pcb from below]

Board: 4 copper layers, 115.0 x 85.0 mm, 90 parts (20 on the bottom side), 46 nets.

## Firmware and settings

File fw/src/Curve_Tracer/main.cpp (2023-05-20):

/**
 * @file        main.cpp
 * @author      Matthew Yu (matthewjkyu@gmail.com)
 * @brief       Controls the IV Curve Tracer and performs PV measurements.
 * @version     0.2.0
 * @date        2022-10-25
 * @copyright   Copyright (c) 2022
 * @note        Use _DEBUG_TUNING flag to perform manual tuning.
 *              Default baud rate is 115200 baud.
 * @todo        - Communication with IV Curve Tracer
 *              - TSL2591 light sensor support through CAN
 *              - RTD temperature sensor support through CAN
 */

#include "mbed.h"

// #define _DEBUG_TUNING_ 1
#define MAJOR_VERSION 0
#define MINOR_VERSION 2
#define PATCH_VERSION 0
#define BAUD_RATE 115200

/** Peripherals. */
static DigitalOut led_heartbeat(D1);
static DigitalOut led_scan(D0);
static AnalogIn sen_voltage(A6);
static AnalogIn sen_current(A0);
static AnalogOut dac_control(A3);
static CAN can(D10, D2);
static CANMessage msg;
static BufferedSerial serial_port(USBTX, USBRX, BAUD_RATE);

/** Tickers. */
static LowPowerTicker tick_heartbeat;
void heartbeat(void) {led_heartbeat = !led_heartbeat;}

FileHandle *mbed::mbed_override_console(int fd) {
    return &serial_port;
}

enum Mode {
    CELL,
    MODULE,
    ARRAY
};

enum EncodingScheme {
    VERBOSE,
};

float cal_dac_control(float in) {
    // TODO: 10/25/22 recheck dac control calibration.
    // const float slope = 9.9539;
    // const float intercept = 0.0583;
    return in;// * slope + intercept;
}

float cal_sen_volt(float in, int num_iterations, enum Mode mode) {
    // TODO: 10/25/22 recheck voltage sensor calibration.
    // + calibration offset for internal PCB resistances causing a voltage drop prior to the voltage sensor. 
    switch (mode) {
        case CELL:
            return 1.1047 * in / num_iterations;
        case MODULE:
            return 5.4591 * in / num_iterations;
        case ARRAY:
            return 111.8247 * in / num_iterations;
        default:
            tick_heartbeat.detach();
            led_heartbeat = 1;
            while (1);
    }
}

float cal_sen_curr(float in, int num_iterations) {
    // TODO: 10/25/22 recheck current sensor calibration.
    return 8.1169 * in / num_iterations + 0.014;
}

int main() {
    tick_heartbeat.attach(&heartbeat, 500ms);
    dac_control = 0.0;

    printf("v%d.%d.%d\r\n", MAJOR_VERSION, MINOR_VERSION, PATCH_VERSION);

#ifdef _DEBUG_TUNING_
    /**
     * Debug mode.
     * Run forwards and backwards along the range where the MOSFET R_ds_on
     * experiences 95% variance.
     *
     * User calibrates sensors for measurement accuracy during the test.
     */
    printf("DEBUG MODE\r\n");
    enum Mode mode = CELL;
    while (1) {
        // Test duration one way: 6.275 seconds
        // 251 steps
        // 25 ms per step
        // 25 substeps per step
        // 1 ms per substep
        #define GATE_OFF                0.25
        #define GATE_ON                 0.50
        #define GATE_STEP               0.001
        #define SETTLING_TIME_US        1000 // us
        #define ITERATIONS              25

        /* Forwards. */
        for (dac_control = GATE_OFF; dac_control <= GATE_ON; dac_control = dac_control + GATE_STEP) {
            float meas_volt = 0.00;
            float meas_curr = 0.00;
            float meas_control = cal_dac_control(dac_control);

            /* SW based sample averaging control. */
            for (uint8_t i = 0; i < ITERATIONS; ++i) {
                wait_us(SETTLING_TIME_US);
                meas_volt += sen_voltage.read();
                meas_curr += sen_current.read();
            }

            meas_volt = cal_sen_volt(meas_volt, ITERATIONS, mode);
            meas_curr = cal_sen_curr(meas_curr, ITERATIONS);

            printf(
                "Gate (V): %f, VSense (V): %f, ISense (A): %f, V*I (W): %f\n",
                meas_control,
                meas_volt,
                meas_curr,
                meas_volt * meas_curr
            );
        }

        /* Backwards. */
        for (dac_control = GATE_ON; dac_control >= GATE_OFF; dac_control = dac_control - GATE_STEP) {
            float meas_volt = 0.00;
            float meas_curr = 0.00;
            float meas_control = cal_dac_control(dac_control);

            /* SW based sample averaging control. */
            for (uint8_t i = 0; i < ITERATIONS; ++i) {
                wait_us(SETTLING_TIME_US);
                meas_volt += sen_voltage.read();
                meas_curr += sen_current.read();
            }

            meas_volt = cal_sen_volt(meas_volt, ITERATIONS, mode);
            meas_curr = cal_sen_curr(meas_curr, ITERATIONS);

            printf(
                "Gate (V): %f, VSense (V): %f, ISense (A): %f, V*I (W): %f\n",
                meas_control,
                meas_volt,
                meas_curr,
                meas_volt * meas_curr
            );
        }

        #undef GATE_OFF
        #undef GATE_ON
        #undef GATE_STEP
        #undef SETTLING_TIME_US
        #undef ITERATIONS
    }
#else
    /* Measurement mode. */
    printf("MEASUREMENT MODE\r\n");

    /* Setup buffer and serial port. */
    #define BUFFER_SIZE 100
    char buffer[BUFFER_SIZE] = { 0 };
    serial_port.set_format(8, BufferedSerial::Even, 1);

    while (1) {
        float GATE_OFF = 0.00;
        float GATE_ON = 1.00;
        float GATE_STEP = 0.001;
        uint8_t ITERATIONS = 1;
        uint32_t SETTLING_TIME_US = 0;
        enum Mode mode = CELL;
        enum EncodingScheme scheme = VERBOSE;
        bool valid_conf = false;
        bool ready = false;

        printf("READY_FOR_TRANSMISSION\r\n");

        /* Read handshake message. */
        while (true) {
            serial_port.read(buffer, BUFFER_SIZE);
            if (false) { // TODO: check for handshake message "OK"
                printf("BEGIN_TRANSMISSION\r\n");
                memset(buffer, '\0', BUFFER_SIZE);
                break;
            }
        }

        /**
         * Expect pv config string in format:
         *   type=$PV_TYPE,sr=[$LOW,$HIGH,$STEP],ni=$NUM_ITER,st_ms=$SETTLE_TIME,enc=$ENC_SCHEME
         */

        /* Get PV type */
        serial_port.read(buffer, BUFFER_SIZE);
        sscanf(buffer,
            "type=%i,sr=[%f,%f,%f],ni=%i,st_ms=%i,enc=%i",
            &mode, &GATE_OFF, &GATE_ON, &GATE_STEP,
            &ITERATIONS, &SETTLING_TIME_US, &scheme);
        memset(buffer, '\0', BUFFER_SIZE);

        /* TODO: check for valid results */

        if (valid_conf && ready) {
            printf("BEGIN_SCAN\n");
            /* Forwards. */
            for (dac_control = GATE_OFF; dac_control <= GATE_ON; dac_control = dac_control + GATE_STEP) {
                float meas_volt = 0.00;
                float meas_curr = 0.00;
                float meas_control = cal_dac_control(dac_control);

                /* SW based sample averaging control. */
                for (uint8_t i = 0; i < ITERATIONS; ++i) {
                    wait_us(SETTLING_TIME_US);
                    meas_volt += sen_voltage.read();
                    meas_curr += sen_current.read();
                }

                meas_volt = cal_sen_volt(meas_volt, ITERATIONS, mode);
                meas_curr = cal_sen_curr(meas_curr, ITERATIONS);

            }

            /* Backwards. */
            for (dac_control = GATE_ON; dac_control >= GATE_OFF; dac_control = dac_control - GATE_STEP) {
                float meas_volt = 0.00;
                float meas_curr = 0.00;
                float meas_control = cal_dac_control(dac_control);

                /* SW based sample averaging control. */
                for (uint8_t i = 0; i < ITERATIONS; ++i) {
                    wait_us(SETTLING_TIME_US);
                    meas_volt += sen_voltage.read();
                    meas_curr += sen_current.read();
                }

                meas_volt = cal_sen_volt(meas_volt, ITERATIONS, mode);
                meas_curr = cal_sen_curr(meas_curr, ITERATIONS);

                switch (scheme) {
                    case VERBOSE:
                        printf(
                            "Gate (V): %f, VSense (V): %f, ISense (A): %f, V*I (W): %f\n",
                            meas_control,
                            meas_volt,
                            meas_curr,
                            meas_volt * meas_curr
                        );
                        break;
                }
            }
            printf("END_SCAN\n");
        }
    }
#endif
}

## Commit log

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2019-02-09 New Debugger for BPS
    [Debugger.kicad_pcb, Debugger.sch]
2019-02-10 Relative addressing for schematic files
    [BPSVoltage.sch]
2019-02-12 Edited inductor choke in BPS master.
    [BPSMaster-B.Cu.gbr, BPSMaster-B.Mask.gbr, BPSMaster-B.Paste.gbr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]
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2019-02-15 Changed the connectors to stack
    [BPSVoltage.kicad_pcb, BPSVoltage.sch]
2019-02-15 New connector for Temperature Board for BPS
    [BPSTemperature2.kicad_pcb, BPSTemperature2.sch, BPSTemperature3.kicad_pcb]
2019-02-16 Edited BPS temperature board to have stackable connectors.
    [BPSTemperature-B.Cu.gbr, BPSTemperature-B.Mask.gbr, BPSTemperature-B.Paste.gbr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]
2019-02-16 Edited comm pins of BPS voltage in case of stacking issues.
    [BPSVoltage-B.Cu.gbr, BPSVoltage-B.Mask.gbr, BPSVoltage-B.Paste.gbr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]
2019-02-16 fix hierarchy
    [file5C5F7A4C.sch]
2019-02-16 NC flags, 3.3v flag, etc.
    [Debugger.sch, file5C5F7A4C.sch]
2019-02-16 Added the USB debugging board design.
    [USBBreakout.kicad_pcb, USBBreakout.sch]
2019-02-19 Added labels to USB breakout.
    [BPSMaster-B.Cu.gbr, BPSMaster-B.Mask.gbr, BPSMaster-B.Paste.gbr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]
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2019-02-23 Updated connectors **Use new netlist**
    [BPSTemperature.kicad_pcb, BPSTemperature.sch]
2019-02-23 fixed bugs
    [BPSTemperature.kicad_pcb]
2019-02-24 Finished debugger layout. Still needs annotations.
    [CAN.sch, Debugger.kicad_pcb, Debugger.sch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]
2019-02-25 Fixed temperature board for BPS.
    [BPSTemperature-B.Cu.gbr, BPSTemperature-B.Mask.gbr, BPSTemperature-B.Paste.gbr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]
2019-02-27 Redid the footprint for the IC, rerouted.
    [BPSVoltage.kicad_pcb, BPSVoltage.sch]
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2019-03-04 board updated with usb c
    [Debugger.kicad_pcb, PowerDist.sch]
2019-03-09 Old Current Sensor Board
    [current sensor board V2.kicad_pcb, current sensor board.kicad_pcb, current sensor board.sch]
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2019-03-18 Changed values of caps in Master board of BPS.
    [CAN.sch, Contactor.sch, Misc.sch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]
2019-03-20 Changed capacitor value for 3.3V regulator in BPS master.
    [PowerDist.sch]
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2019-03-25 footprint error fixed in voltage board. Created new gerber files.
    [BPSVoltage-B.Cu.gbr, BPSVoltage-B.Mask.gbr, BPSVoltage-B.Paste.gbr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]
2019-03-30 Fixed some stuff
    [Debugger.kicad_pcb, PowerDist.sch]
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2019-03-30 Modified Low-Pass Filter values
    [BPSTemperature.sch]
2019-03-30 12V and gndpower planes
    [Debugger.kicad_pcb]
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2019-04-06 Temperature sensor distribution board
    [TemperaturePower-B.Cu.gbr, TemperaturePower-B.Mask.gbr, TemperaturePower-B.Paste.gbr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]
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2019-06-08 Edited temmperature board to have reset pin to high.
    [BPSTemperature-B.Cu.gbr, BPSTemperature-B.Mask.gbr, BPSTemperature-B.Paste.gbr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]
2019-07-27 Adds Nucleo version of master board.
    [BPS-Nucleo.kicad_pcb, BPS-Nucleo.sch, BPSMaster.sch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]
2019-08-31 Adds Display board schematics.
    [BPSDisplay.kicad_pcb, BPSDisplay.sch, CAN.sch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]
2019-08-31 Some suggested changes and smaller
    [current sensor board V2.kicad_pcb]
2019-08-31 Creates schematics for display.
    [BPSDisplay.kicad_pcb, BPSDisplay.sch, CAN.sch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]
2019-08-31 reduced size of current board
    [BPSCurrent.kicad_pcb, BPSCurrent.sch, current sensor board V2.kicad_pcb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]
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2019-09-07 New Current Board, Removed sensing, new connector
    [current sensor board V2.kicad_pcb, current sensor board.sch]
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2019-09-14 worked on pcb layout and schematic
    [BPS-Nucleo.kicad_pcb, BPS-Nucleo.sch, CAN.sch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]
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2019-09-21 Added Mounting Holes to Temperature Power Board
    [TemperaturePower-B.Cu.gbr, TemperaturePower-B.Mask.gbr, TemperaturePower-B.Paste.gbr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]
2019-09-21 Finish Display board, generate Gerbers.
    [BPSDisplay.kicad_pcb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]
2019-10-11 Creates gerber files for display board and master.
    [BPSDisplay-B_Cu.gbr, BPSDisplay-B_Mask.gbr, BPSDisplay-B_Paste.gbr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]
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2019-10-12 Change capacitor value for VCAP on master board to 4.7uF
    [BPSMaster.sch]
2019-10-12 Fix the backwardness to the Temperature power board
    [TemperaturePower-B_Cu.gbr, TemperaturePower-B_Mask.gbr, TemperaturePower-B_Paste.gbr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]
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2019-10-27 Cleans repo to only contain most recent design.
    [BOM.xlsx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]
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2019-12-25 Edits master board to not have temperature board pinouts.
    [BPSMaster.kicad_pcb, BPSMaster.sch, BPSMinion.kicad_pcb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]
2020-01-14 Adds contactor driver board for precharge motor and array.
    [ContactorDriver.kicad_pcb, ContactorDriver.sch]
2020-01-25 Adds BPS master board with no temperature brd electronics and ContactorDriver for dashboard to control.
    [BPSMaster.kicad_pcb, BPSMaster.sch, CAN.sch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]
2020-01-25 Adds resistor mount. Need to add pheonix connector.
    [BPSMaster.kicad_pcb, ContactorDriver.kicad_pcb]
2020-01-31 Adds final BPS leader board and completed Contactor/precharge board.
    [BPSMaster-B_Cu.gbr, BPSMaster-B_Mask.gbr, BPSMaster-B_Paste.gbr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]
2020-02-01 Adds hole dimenions silkscreen text for contactor driver board.
    [ContactorDriver-B_Cu.gbr, ContactorDriver-B_Mask.gbr, ContactorDriver-B_Paste.gbr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]
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2020-08-02 Current board (#41)
    * Adds current board project
    * Found footprint and symbol
    * Finished basic connections. Still need to add DC-DC converter and connection for interrupts if needed.
    * Completes schematic of current board
    * Adds AS8510 into utsvt-bps.lib
    * Edits name of mounting holes to standardized M3 screw size
    * Updates footprint for 470pF capacitor
    * Completes current board schematic and starts PCB
    * Organizes and edits PCB layout
    * Worked on layout of board
    * Finishes PCB layout of current board
    * Adds keepout zone for the transformer and the dimensions
    * Fixes unconnection error of pcb
    * Edits LTC6820 symbol, generates netlist, and fixes schemati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
    [CurrentBoard.kicad_pcb, CurrentBoard.sch]
2020-08-02 Leader board (#42)
    * Creates fan brd interface schematics and updates symbols/footprints related to the leader board
    * Finishes schematics for bps leader board
    * Renames bps master to bps leader:
    * Places most components of leader board in their respective locations with nothing traced
    * Adds power planes
    * Everything traced in leader board except for power circuitry
    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
    [BPSLeader.kicad_pcb, BPSLeader.sch, BPSMaster.kicad_pcb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]
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2020-08-09 CAN updated, needs bugfixes and footprint review.
    [IV Curve Tracer.kicad_pcb, IV Curve Tracer.sch]
2020-08-12 proof checked, drc run and mounting holes added.
    [IV Curve Tracer.kicad_pcb, IV Curve Tracer.sch]
2020-08-21 rebuilt with MOSFET footprint flipped, traces rewired, and dot for every smd component where 1st pin is not obvious
    [IV Curve Tracer-B_Cu.gbr, IV Curve Tracer-B_Mask.gbr, IV Curve Tracer-B_Paste.gbr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]
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2020-12-16 Major Curve Tracer Board overhaul. Schematic advanced to Rev 1.1.0. Layout advanced to Rev 1.1.0. Parts list advanced to Rev 1.1.0.
    [IV Curve Tracer-B_Cu.gbr, IV Curve Tracer-B_Mask.gbr, IV Curve Tracer-B_Paste.gbr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]
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2021-10-21 added bodge notes to current version Curve Tracer
    [IV Curve Tracer-B_Cu.gbr, IV Curve Tracer-B_Mask.gbr, IV Curve Tracer-B_Paste.gbr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]
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2022-02-08 swapped INA210 to SC70 footprint, added gate resistor
    [IV Curve Tracer-B_Cu.gbr, IV Curve Tracer-B_Mask.gbr, IV Curve Tracer-B_Paste.gbr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]
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2022-02-17 gerber rebuilds to fix JLCPCB error
    [CurveTracer_v1.2.0_BoM.xlsx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]
2023-05-20 cleanup and fix errors for v1.3.0, proposed v1.4.0
    [IV Curve Tracer-CuBottom.gbr, IV Curve Tracer-CuTop.gbr, IV Curve Tracer-EdgeCuts.gbr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]
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
